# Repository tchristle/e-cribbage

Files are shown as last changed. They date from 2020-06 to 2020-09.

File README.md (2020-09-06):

# e-cribbage
SMT LED Cribbage Board
3D

**To-Do List**
**-----------------------------------------------------------------**
* Schematic
	- [x] assign different symbols to P1 and P2 LEDs
	- [x] assign correct parts numbers to switch and CR2032 symbols
	- [ ] assign final values to LED current limiting resistor
* Layout
	- [x] modify CR2032 footprint to match selected clip
	- [x] modify B5 footprint to match selected slide switch
	- [x] assign common footprint to all capacitors
	- [x] update footprint for S1-S4 tactile push buttons
	- [x] generate gerbers and drill
	- [ ] fix up silk screen on foot prints
* Mechanical
	- [ ] design acrylic cover
	- [ ] update view showing current buttons
* BOM
	- [x] generate BOM from KiCAD schematic
	- [ ] attach Digikey PNs to BOM
	- [X] down select LEDs and colors
	- [x] down select slide switch
	- [x] down select tactile push button
	- [ ] generate Digikey cart from BOM
	- [x] get pricing on PCB
	- [x] get pricing on stencils
	- [ ] get pricing on pick and place assembly
* Software
	- [ ] debug flash store and recall functions
	- [ ] replace for loops and counters with timers in LPM0
	- [X] implement peg swap timer
	- [X] implement Elapsed Time Indicator
* Prototype
	- [x] drive sample LEDs with limit resistor to set brightness level
	- [X] analyze battery life with CR2032 cell
	- [x] interface ez430 with single shifter register

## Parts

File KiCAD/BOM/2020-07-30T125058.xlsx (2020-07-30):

Index | Quantity | Part Number | Manufacturer Part Number | Description | Customer Reference | Available | Backorder | Unit Price | Extended Price USD
1 | 10 | 296-19731-1-ND | MSP430F2012IPWR | IC MCU 16BIT 2KB FLASH 14TSSOP | U2 | 10 | 0 | 1.982 | 19.82
2 | 100 | 296-23258-1-ND | SN74HC595PWR | IC 8BIT SHIFT REGISTER 16-TSSOP | U1,U3-U31 | 100 | 0 | 0.256 | 25.60
3 | 10 | WM17141CT-ND | 0473460001 | CONN RCPT USB2.0 MICRO B SMD R/A | J2 | 10 | 0 | 0.921 | 9.21
4 | 10 | 296-35591-1-ND | TLV71333PDBVR | IC REG LINEAR 3.3V 150MA SOT23-5 | U41 | 10 | 0 | 0.282 | 2.82
5 | 10 | 296-38579-1-ND | TPS22929DDBVR | IC PWR SWITCH P-CHAN 1:1 SOT23-6 | U33 | 10 | 0 | 0.667 | 6.67
6 | 40 | 296-11601-1-ND | SN74LVC1G08DBVR | IC GATE AND 1CH 2-INP SOT23-5 | U32, U34-U40 | 40 | 0 | 0.198 | 7.92
7 | 100 | 399-1099-1-ND | C0603C104M4RACTU | CAP CER 0.1UF 16V X7R 0603 | C1-C39 | 100 | 0 | 0.0154 | 1.54
8 | 20 | 399-7847-1-ND | C0603C105K4RACTU | CAP CER 1UF 16V X7R 0603 | C40-C43 | 20 | 0 | 0.084 | 1.68
9 | 10 | BC-2003-G-TR-CT-ND | BC-2003-G-TR | CR2032 CONTACT STRAP IN GOLD | BAT1 | 10 | 0 | 0.841 | 8.41
10 | 100 | 541-4021-1-ND | CRCW060347K0FKEAC | RES SMD 47K OHM 1% 1/10W 0603 | R251 | 100 | 0 | 0.0134 | 1.34
11 | 100 | 541-10.0KHCT-ND | CRCW060310K0FKEA | RES SMD 10K OHM 1% 1/10W 0603 | R121-R240 | 100 | 0 | 0.0134 | 1.34
12 | 20 | P189-ND | CR2032 | BATTERY LITHIUM 3V COIN 20MM |  | 20 | 0 | 0.2635 | 5.27
13 | 12 | CKN4080-ND | KS11R22CQD | SWITCH PUSH SPST-NO 0.025A 50V | S1-S4 | 12 | 0 | 1.804 | 21.65
14 | 10 | CKN10720CT-ND | JS102011JAQN | SWITCH SLIDE SPDT 300MA 6V | S5 | 10 | 0 | 0.67 | 6.70
15 | 100 | 541-768HCT-ND | CRCW0603768RFKEA | RES SMD 768 OHM 1% 1/10W 0603 | R121-R240 | 100 | 0 | 0.0134 | 1.34

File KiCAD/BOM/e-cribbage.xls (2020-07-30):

Source: |  | /home/travis/e-cribbage/KiCAD/e-cribbage.sch
Date: |  | Wed 29 Jul 2020 05:02:40 PM CDT
Tool: |  | Eeschema 5.1.4+dfsg1-1
Component Count: |  | 577
Ref | QTY | Value | Footprint | Datasheet | Manufacturer | Vendor
BAT1 | 1 | BS-7 | Battery_Holders:Keystone_1058_1x2032-CoinCell | http://www.memoryprotectiondevices.com/datasheets/BS-7-datasheet.pdf | MPD (Memory Protection Devices)
C1-C39 | 39 | 0.1uF | Capacitor_SMD:C_0603_1608Metric_Pad1.05x0.95mm_HandSolder | ~
C40-C43 | 4 | 1.0uF | Capacitor_SMD:C_0603_1608Metric_Pad1.05x0.95mm_HandSolder | ~
D1-D120 | 120 | LED1 | e-cribbage:LED_0603 | ~
D121-D240 | 120 | LED2 | e-cribbage:LED_0603 | ~
J1 | 1 | Conn_01x04_Female | Connector_PinHeader_1.27mm:PinHeader_1x04_P1.27mm_Vertical | ~
J2 | 1 | USB_B_Micro | Connector_USB:USB_Micro-B_Molex_47346-0001 | ~
R1-R120 | 120 | 1k | e-cribbage:R_0603 | ~
R121-R240 | 120 | 1k | e-cribbage:R_0603 | ~
R243, R244, R246, R247 | 4 | 10k | e-cribbage:R_0603 | ~
R251 | 1 | 47k | e-cribbage:R_0603 | ~
S1-S4 | 4 | GPTS203211B | Buttons_Switches_SMD:SW_SPST_B3SL-1002P | http://switches-connectors-custom.cwind.com/Asset/GPTS203211BR2.pdf | CW Industries
S5 | 1 | EG1218 | Button_Switch_SMD:SW_SPDT_CK-JS102011SAQN | http://spec_sheets.e-switch.com/specs/P040040.pdf | E-Switch
U1,U3-U31 | 30 | 74HC595D_118 | digikey-footprints:TSSOP-16_W4.40mm | https://assets.nexperia.com/documents/data-sheet/74HC_HCT595.pdf | Nexperia USA Inc.
U2 | 1 | MSP430F2012IPW | digikey-footprints:TSSOP-14_W4.4mm | http://www.ti.com/lit/ds/symlink/msp430f2012.pdf
U32, U34-U40 | 8 | SN74LVC1G08DBVR | digikey-footprints:SOT-753 | http://www.ti.com/general/docs/suppproductinfo.tsp?distId=10 | Texas Instruments
U41 | 1 | TLV71333PDBV | Package_TO_SOT_SMD:SOT-23-5 | http://www.ti.com/lit/ds/symlink/tlv713p.pdf
U33 | 1 | TPS22929D | Package_TO_SOT_SMD:SOT-23-6 | http://www.ti.com/lit/ds/symlink/tps22929d.pdf

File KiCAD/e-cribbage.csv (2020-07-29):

Source: | /home/travis/e-cribbage/KiCAD/e-cribbage.sch
Date: | Wed 29 Jul 2020 05:02:40 PM CDT
Tool: | Eeschema 5.1.4+dfsg1-1
Component Count: | 577
Ref | Value | Footprint | Datasheet | Manufacturer | Vendor
BAT1 | BS-7 | Battery_Holders:Keystone_1058_1x2032-CoinCell | http://www.memoryprotectiondevices.com/datasheets/BS-7-datasheet.pdf | MPD (Memory Protection Devices)
C1 | 1.0uF | Capacitor_SMD:C_0603_1608Metric_Pad1.05x0.95mm_HandSolder | ~
C2 | 1.0uF | Capacitor_SMD:C_0603_1608Metric_Pad1.05x0.95mm_HandSolder | ~
C3 | 1.0uF | Capacitor_SMD:C_0603_1608Metric_Pad1.05x0.95mm_HandSolder | ~
C4 | 1.0uF | Capacitor_SMD:C_0603_1608Metric_Pad1.05x0.95mm_HandSolder | ~
C5 | 1.0uF | Capacitor_SMD:C_0603_1608Metric_Pad1.05x0.95mm_HandSolder | ~
C6 | 1.0uF | Capacitor_SMD:C_0603_1608Metric_Pad1.05x0.95mm_HandSolder | ~
C7 | 1.0uF | Capacitor_SMD:C_0603_1608Metric_Pad1.05x0.95mm_HandSolder | ~
C8 | 1.0uF | Capacitor_SMD:C_0603_1608Metric_Pad1.05x0.95mm_HandSolder | ~
C9 | 1.0uF | Capacitor_SMD:C_0603_1608Metric_Pad1.05x0.95mm_HandSolder | ~
C10 | 1.0uF | Capacitor_SMD:C_0603_1608Metric_Pad1.05x0.95mm_HandSolder | ~
C11 | 1.0uF | Capacitor_SMD:C_0603_1608Metric_Pad1.05x0.95mm_HandSolder | ~
C12 | 1.0uF | Capacitor_SMD:C_0603_1608Metric_Pad1.05x0.95mm_HandSolder | ~
C13 | 1.0uF | Capacitor_SMD:C_0603_1608Metric_Pad1.05x0.95mm_HandSolder | ~
C14 | 1.0uF | Capacitor_SMD:C_0603_1608Metric_Pad1.05x0.95mm_HandSolder | ~
C15 | 1.0uF | Capacitor_SMD:C_0603_1608Metric_Pad1.05x0.95mm_HandSolder | ~
C16 | 1.0uF | Capacitor_SMD:C_0603_1608Metric_Pad1.05x0.95mm_HandSolder | ~
C17 | 1.0uF | Capacitor_SMD:C_0603_1608Metric_Pad1.05x0.95mm_HandSolder | ~
C18 | 1.0uF | Capacitor_SMD:C_0603_1608Metric_Pad1.05x0.95mm_HandSolder | ~
C19 | 1.0uF | Capacitor_SMD:C_0603_1608Metric_Pad1.05x0.95mm_HandSolder | ~
C20 | 1.0uF | Capacitor_SMD:C_0603_1608Metric_Pad1.05x0.95mm_HandSolder | ~
C21 | 1.0uF | Capacitor_SMD:C_0603_1608Metric_Pad1.05x0.95mm_HandSolder | ~
C22 | 1.0uF | Capacitor_SMD:C_0603_1608Metric_Pad1.05x0.95mm_HandSolder | ~
C23 | 1.0uF | Capacitor_SMD:C_0603_1608Metric_Pad1.05x0.95mm_HandSolder | ~
C24 | 1.0uF | Capacitor_SMD:C_0603_1608Metric_Pad1.05x0.95mm_HandSolder | ~
C25 | 1.0uF | Capacitor_SMD:C_0603_1608Metric_Pad1.05x0.95mm_HandSolder | ~
C26 | 1.0uF | Capacitor_SMD:C_0603_1608Metric_Pad1.05x0.95mm_HandSolder | ~
C27 | 1.0uF | Capacitor_SMD:C_0603_1608Metric_Pad1.05x0.95mm_HandSolder | ~
C28 | 1.0uF | Capacitor_SMD:C_0603_1608Metric_Pad1.05x0.95mm_HandSolder | ~
C29 | 1.0uF | Capacitor_SMD:C_0603_1608Metric_Pad1.05x0.95mm_HandSolder | ~
C30 | 1.0uF | Capacitor_SMD:C_0603_1608Metric_Pad1.05x0.95mm_HandSolder | ~
C31 | 1.0uF | Capacitor_SMD:C_0603_1608Metric_Pad1.05x0.95mm_HandSolder | ~
C32 | 1.0uF | Capacitor_SMD:C_0603_1608Metric_Pad1.05x0.95mm_HandSolder | ~
C33 | 1.0uF | Capacitor_SMD:C_0603_1608Metric_Pad1.05x0.95mm_HandSolder | ~
C34 | 1.0uF | Capacitor_SMD:C_0603_1608Metric_Pad1.05x0.95mm_HandSolder | ~
C35 | 1.0uF | Capacitor_SMD:C_0603_1608Metric_Pad1.05x0.95mm_HandSolder | ~
C36 | 1.0uF | Capacitor_SMD:C_0603_1608Metric_Pad1.05x0.95mm_HandSolder | ~
C37 | 1.0uF | Capacitor_SMD:C_0603_1608Metric_Pad1.05x0.95mm_HandSolder | ~
C38 | 1.0uF | Capacitor_SMD:C_0603_1608Metric_Pad1.05x0.95mm_HandSolder | ~
C39 | 1.0uF | Capacitor_SMD:C_0603_1608Metric_Pad1.05x0.95mm_HandSolder | ~
C40 | 1.0uF | Capacitor_SMD:C_0603_1608Metric_Pad1.05x0.95mm_HandSolder | ~
C41 | 1.0uF | Capacitor_SMD:C_0603_1608Metric_Pad1.05x0.95mm_HandSolder | ~
C42 | 1.0uF | Capacitor_SMD:C_0603_1608Metric_Pad1.05x0.95mm_HandSolder | ~
C43 | 1.0uF | Capacitor_SMD:C_0603_1608Metric_Pad1.05x0.95mm_HandSolder | ~
D1 | LED1 | e-cribbage:LED_0603 | ~
D2 | LED1 | e-cribbage:LED_0603 | ~
D3 | LED1 | e-cribbage:LED_0603 | ~
D4 | LED1 | e-cribbage:LED_0603 | ~
D5 | LED1 | e-cribbage:LED_0603 | ~
D6 | LED1 | e-cribbage:LED_0603 | ~
D7 | LED1 | e-cribbage:LED_0603 | ~
D8 | LED1 | e-cribbage:LED_0603 | ~
D9 | LED1 | e-cribbage:LED_0603 | ~
D10 | LED1 | e-cribbage:LED_0603 | ~
D11 | LED1 | e-cribbage:LED_0603 | ~
D12 | LED1 | e-cribbage:LED_0603 | ~
D13 | LED1 | e-cribbage:LED_0603 | ~
D14 | LED1 | e-cribbage:LED_0603 | ~
D15 | LED1 | e-cribbage:LED_0603 | ~
D16 | LED1 | e-cribbage:LED_0603 | ~
D17 | LED1 | e-cribbage:LED_0603 | ~
D18 | LED1 | e-cribbage:LED_0603 | ~
D19 | LED1 | e-cribbage:LED_0603 | ~
D20 | LED1 | e-cribbage:LED_0603 | ~
D21 | LED1 | e-cribbage:LED_0603 | ~
D22 | LED1 | e-cribbage:LED_0603 | ~
D23 | LED1 | e-cribbage:LED_0603 | ~
D24 | LED1 | e-cribbage:LED_0603 | ~
D25 | LED1 | e-cribbage:LED_0603 | ~
D26 | LED1 | e-cribbage:LED_0603 | ~
D27 | LED1 | e-cribbage:LED_0603 | ~
D28 | LED1 | e-cribbage:LED_0603 | ~
D29 | LED1 | e-cribbage:LED_0603 | ~
D30 | LED1 | e-cribbage:LED_0603 | ~
D31 | LED1 | e-cribbage:LED_0603 | ~
D32 | LED1 | e-cribbage:LED_0603 | ~
D33 | LED1 | e-cribbage:LED_0603 | ~
D34 | LED1 | e-cribbage:LED_0603 | ~
D35 | LED1 | e-cribbage:LED_0603 | ~
D36 | LED1 | e-cribbage:LED_0603 | ~
D37 | LED1 | e-cribbage:LED_0603 | ~
D38 | LED1 | e-cribbage:LED_0603 | ~
D39 | LED1 | e-cribbage:LED_0603 | ~
D40 | LED1 | e-cribbage:LED_0603 | ~
D41 | LED1 | e-cribbage:LED_0603 | ~
D42 | LED1 | e-cribbage:LED_0603 | ~
D43 | LED1 | e-cribbage:LED_0603 | ~
D44 | LED1 | e-cribbage:LED_0603 | ~
D45 | LED1 | e-cribbage:LED_0603 | ~
D46 | LED1 | e-cribbage:LED_0603 | ~
D47 | LED1 | e-cribbage:LED_0603 | ~
D48 | LED1 | e-cribbage:LED_0603 | ~
D49 | LED1 | e-cribbage:LED_0603 | ~
D50 | LED1 | e-cribbage:LED_0603 | ~
D51 | LED1 | e-cribbage:LED_0603 | ~
D52 | LED1 | e-cribbage:LED_0603 | ~
D53 | LED1 | e-cribbage:LED_0603 | ~
D54 | LED1 | e-cribbage:LED_0603 | ~
D55 | LED1 | e-cribbage:LED_0603 | ~
D56 | LED1 | e-cribbage:LED_0603 | ~
D57 | LED1 | e-cribbage:LED_0603 | ~
D58 | LED1 | e-cribbage:LED_0603 | ~
D59 | LED1 | e-cribbage:LED_0603 | ~
D60 | LED1 | e-cribbage:LED_0603 | ~
D61 | LED1 | e-cribbage:LED_0603 | ~
D62 | LED1 | e-cribbage:LED_0603 | ~
D63 | LED1 | e-cribbage:LED_0603 | ~
D64 | LED1 | e-cribbage:LED_0603 | ~
D65 | LED1 | e-cribbage:LED_0603 | ~
D66 | LED1 | e-cribbage:LED_0603 | ~
D67 | LED1 | e-cribbage:LED_0603 | ~
D68 | LED1 | e-cribbage:LED_0603 | ~
D69 | LED1 | e-cribbage:LED_0603 | ~
D70 | LED1 | e-cribbage:LED_0603 | ~
D71 | LED1 | e-cribbage:LED_0603 | ~
D72 | LED1 | e-cribbage:LED_0603 | ~
D73 | LED1 | e-cribbage:LED_0603 | ~
D74 | LED1 | e-cribbage:LED_0603 | ~
D75 | LED1 | e-cribbage:LED_0603 | ~
D76 | LED1 | e-cribbage:LED_0603 | ~
D77 | LED1 | e-cribbage:LED_0603 | ~
D78 | LED1 | e-cribbage:LED_0603 | ~
D79 | LED1 | e-cribbage:LED_0603 | ~
D80 | LED1 | e-cribbage:LED_0603 | ~
D81 | LED1 | e-cribbage:LED_0603 | ~
D82 | LED1 | e-cribbage:LED_0603 | ~
D83 | LED1 | e-cribbage:LED_0603 | ~
D84 | LED1 | e-cribbage:LED_0603 | ~
D85 | LED1 | e-cribbage:LED_0603 | ~
D86 | LED1 | e-cribbage:LED_0603 | ~
D87 | LED1 | e-cribbage:LED_0603 | ~
D88 | LED1 | e-cribbage:LED_0603 | ~
D89 | LED1 | e-cribbage:LED_0603 | ~
D90 | LED1 | e-cribbage:LED_0603 | ~
D91 | LED1 | e-cribbage:LED_0603 | ~
D92 | LED1 | e-cribbage:LED_0603 | ~
D93 | LED1 | e-cribbage:LED_0603 | ~
D94 | LED1 | e-cribbage:LED_0603 | ~
D95 | LED1 | e-cribbage:LED_0603 | ~
D96 | LED1 | e-cribbage:LED_0603 | ~
D97 | LED1 | e-cribbage:LED_0603 | ~
D98 | LED1 | e-cribbage:LED_0603 | ~
D99 | LED1 | e-cribbage:LED_0603 | ~
D100 | LED1 | e-cribbage:LED_0603 | ~
D101 | LED1 | e-cribbage:LED_0603 | ~
D102 | LED1 | e-cribbage:LED_0603 | ~
D103 | LED1 | e-cribbage:LED_0603 | ~
D104 | LED1 | e-cribbage:LED_0603 | ~
D105 | LED1 | e-cribbage:LED_0603 | ~
D106 | LED1 | e-cribbage:LED_0603 | ~
D107 | LED1 | e-cribbage:LED_0603 | ~
D108 | LED1 | e-cribbage:LED_0603 | ~
D109 | LED1 | e-cribbage:LED_0603 | ~
D110 | LED1 | e-cribbage:LED_0603 | ~
D111 | LED1 | e-cribbage:LED_0603 | ~
D112 | LED1 | e-cribbage:LED_0603 | ~
D113 | LED1 | e-cribbage:LED_0603 | ~
D114 | LED1 | e-cribbage:LED_0603 | ~
D115 | LED1 | e-cribbage:LED_0603 | ~
D116 | LED1 | e-cribbage:LED_0603 | ~
D117 | LED1 | e-cribbage:LED_0603 | ~
D118 | LED1 | e-cribbage:LED_0603 | ~
D119 | LED1 | e-cribbage:LED_0603 | ~
D120 | LED1 | e-cribbage:LED_0603 | ~
D121 | LED2 | e-cribbage:LED_0603 | ~
D122 | LED2 | e-cribbage:LED_0603 | ~
D123 | LED2 | e-cribbage:LED_0603 | ~
D124 | LED2 | e-cribbage:LED_0603 | ~
D125 | LED2 | e-cribbage:LED_0603 | ~
D126 | LED2 | e-cribbage:LED_0603 | ~
D127 | LED2 | e-cribbage:LED_0603 | ~
D128 | LED2 | e-cribbage:LED_0603 | ~
D129 | LED2 | e-cribbage:LED_0603 | ~
D130 | LED2 | e-cribbage:LED_0603 | ~
D131 | LED2 | e-cribbage:LED_0603 | ~
D132 | LED2 | e-cribbage:LED_0603 | ~
D133 | LED2 | e-cribbage:LED_0603 | ~
D134 | LED2 | e-cribbage:LED_0603 | ~
D135 | LED2 | e-cribbage:LED_0603 | ~
D136 | LED2 | e-cribbage:LED_0603 | ~
D137 | LED2 | e-cribbage:LED_0603 | ~
D138 | LED2 | e-cribbage:LED_0603 | ~
D139 | LED2 | e-cribbage:LED_0603 | ~
D140 | LED2 | e-cribbage:LED_0603 | ~
D141 | LED2 | e-cribbage:LED_0603 | ~
D142 | LED2 | e-cribbage:LED_0603 | ~
D143 | LED2 | e-cribbage:LED_0603 | ~
D144 | LED2 | e-cribbage:LED_0603 | ~
D145 | LED2 | e-cribbage:LED_0603 | ~
D146 | LED2 | e-cribbage:LED_0603 | ~
D147 | LED2 | e-cribbage:LED_0603 | ~
D148 | LED2 | e-cribbage:LED_0603 | ~
D149 | LED2 | e-cribbage:LED_0603 | ~
D150 | LED2 | e-cribbage:LED_0603 | ~
D151 | LED2 | e-cribbage:LED_0603 | ~
D152 | LED2 | e-cribbage:LED_0603 | ~
D153 | LED2 | e-cribbage:LED_0603 | ~
D154 | LED2 | e-cribbage:LED_0603 | ~
D155 | LED2 | e-cribbage:LED_0603 | ~
D156 | LED2 | e-cribbage:LED_0603 | ~
D157 | LED2 | e-cribbage:LED_0603 | ~
D158 | LED2 | e-cribbage:LED_0603 | ~
D159 | LED2 | e-cribbage:LED_0603 | ~
D160 | LED2 | e-cribbage:LED_0603 | ~
D161 | LED2 | e-cribbage:LED_0603 | ~
D162 | LED2 | e-cribbage:LED_0603 | ~
D163 | LED2 | e-cribbage:LED_0603 | ~
D164 | LED2 | e-cribbage:LED_0603 | ~
D165 | LED2 | e-cribbage:LED_0603 | ~
D166 | LED2 | e-cribbage:LED_0603 | ~
D167 | LED2 | e-cribbage:LED_0603 | ~
D168 | LED2 | e-cribbage:LED_0603 | ~
D169 | LED2 | e-cribbage:LED_0603 | ~
D170 | LED2 | e-cribbage:LED_0603 | ~
D171 | LED2 | e-cribbage:LED_0603 | ~
D172 | LED2 | e-cribbage:LED_0603 | ~
D173 | LED2 | e-cribbage:LED_0603 | ~
D174 | LED2 | e-cribbage:LED_0603 | ~
D175 | LED2 | e-cribbage:LED_0603 | ~
D176 | LED2 | e-cribbage:LED_0603 | ~
D177 | LED2 | e-cribbage:LED_0603 | ~
D178 | LED2 | e-cribbage:LED_0603 | ~
D179 | LED2 | e-cribbage:LED_0603 | ~
D180 | LED2 | e-cribbage:LED_0603 | ~
D181 | LED2 | e-cribbage:LED_0603 | ~
D182 | LED2 | e-cribbage:LED_0603 | ~
D183 | LED2 | e-cribbage:LED_0603 | ~
D184 | LED2 | e-cribbage:LED_0603 | ~
D185 | LED2 | e-cribbage:LED_0603 | ~
D186 | LED2 | e-cribbage:LED_0603 | ~
D187 | LED2 | e-cribbage:LED_0603 | ~
D188 | LED2 | e-cribbage:LED_0603 | ~
D189 | LED2 | e-cribbage:LED_0603 | ~
D190 | LED2 | e-cribbage:LED_0603 | ~
D191 | LED2 | e-cribbage:LED_0603 | ~
D192 | LED2 | e-cribbage:LED_0603 | ~
D193 | LED2 | e-cribbage:LED_0603 | ~
D194 | LED2 | e-cribbage:LED_0603 | ~
D195 | LED2 | e-cribbage:LED_0603 | ~
D196 | LED2 | e-cribbage:LED_0603 | ~
D197 | LED2 | e-cribbage:LED_0603 | ~
D198 | LED2 | e-cribbage:LED_0603 | ~
D199 | LED2 | e-cribbage:LED_0603 | ~
D200 | LED2 | e-cribbage:LED_0603 | ~
D201 | LED2 | e-cribbage:LED_0603 | ~
D202 | LED2 | e-cribbage:LED_0603 | ~
D203 | LED2 | e-cribbage:LED_0603 | ~
D204 | LED2 | e-cribbage:LED_0603 | ~
D205 | LED2 | e-cribbage:LED_0603 | ~
D206 | LED2 | e-cribbage:LED_0603 | ~
D207 | LED2 | e-cribbage:LED_0603 | ~
D208 | LED2 | e-cribbage:LED_0603 | ~
D209 | LED2 | e-cribbage:LED_0603 | ~
D210 | LED2 | e-cribbage:LED_0603 | ~
D211 | LED2 | e-cribbage:LED_0603 | ~
D212 | LED2 | e-cribbage:LED_0603 | ~
D213 | LED2 | e-cribbage:LED_0603 | ~
D214 | LED2 | e-cribbage:LED_0603 | ~
D215 | LED2 | e-cribbage:LED_0603 | ~
D216 | LED2 | e-cribbage:LED_0603 | ~
D217 | LED2 | e-cribbage:LED_0603 | ~
D218 | LED2 | e-cribbage:LED_0603 | ~
D219 | LED2 | e-cribbage:LED_0603 | ~
D220 | LED2 | e-cribbage:LED_0603 | ~
D221 | LED2 | e-cribbage:LED_0603 | ~
D222 | LED2 | e-cribbage:LED_0603 | ~
D223 | LED2 | e-cribbage:LED_0603 | ~
D224 | LED2 | e-cribbage:LED_0603 | ~
D225 | LED2 | e-cribbage:LED_0603 | ~
D226 | LED2 | e-cribbage:LED_0603 | ~
D227 | LED2 | e-cribbage:LED_0603 | ~
D228 | LED2 | e-cribbage:LED_0603 | ~
D229 | LED2 | e-cribbage:LED_0603 | ~
D230 | LED2 | e-cribbage:LED_0603 | ~
D231 | LED2 | e-cribbage:LED_0603 | ~
D232 | LED2 | e-cribbage:LED_0603 | ~
D233 | LED2 | e-cribbage:LED_0603 | ~
D234 | LED2 | e-cribbage:LED_0603 | ~
D235 | LED2 | e-cribbage:LED_0603 | ~
D236 | LED2 | e-cribbage:LED_0603 | ~
D237 | LED2 | e-cribbage:LED_0603 | ~
D238 | LED2 | e-cribbage:LED_0603 | ~
D239 | LED2 | e-cribbage:LED_0603 | ~
D240 | LED2 | e-cribbage:LED_0603 | ~
J1 | Conn_01x04_Female | Connector_PinHeader_1.27mm:PinHeader_1x04_P1.27mm_Vertical | ~
J2 | USB_B_Micro | Connector_USB:USB_Micro-B_Molex_47346-0001 | ~
R1 | 1k | e-cribbage:R_0603 | ~
R2 | 1k | e-cribbage:R_0603 | ~
R3 | 1k | e-cribbage:R_0603 | ~
R4 | 1k | e-cribbage:R_0603 | ~
R5 | 1k | e-cribbage:R_0603 | ~
R6 | 1k | e-cribbage:R_0603 | ~
R7 | 1k | e-cribbage:R_0603 | ~
R8 | 1k | e-cribbage:R_0603 | ~
R9 | 1k | e-cribbage:R_0603 | ~
R10 | 1k | e-cribbage:R_0603 | ~
R11 | 1k | e-cribbage:R_0603 | ~
R12 | 1k | e-cribbage:R_0603 | ~
R13 | 1k | e-cribbage:R_0603 | ~
R14 | 1k | e-cribbage:R_0603 | ~
R15 | 1k | e-cribbage:R_0603 | ~
R16 | 1k | e-cribbage:R_0603 | ~
R17 | 1k | e-cribbage:R_0603 | ~
R18 | 1k | e-cribbage:R_0603 | ~
R19 | 1k | e-cribbage:R_0603 | ~
R20 | 1k | e-cribbage:R_0603 | ~
R21 | 1k | e-cribbage:R_0603 | ~
R22 | 1k | e-cribbage:R_0603 | ~
R23 | 1k | e-cribbage:R_0603 | ~
R24 | 1k | e-cribbage:R_0603 | ~
R25 | 1k | e-cribbage:R_0603 | ~
R26 | 1k | e-cribbage:R_0603 | ~
R27 | 1k | e-cribbage:R_0603 | ~
R28 | 1k | e-cribbage:R_0603 | ~
R29 | 1k | e-cribbage:R_0603 | ~
R30 | 1k | e-cribbage:R_0603 | ~
R31 | 1k | e-cribbage:R_0603 | ~
R32 | 1k | e-cribbage:R_0603 | ~
R33 | 1k | e-cribbage:R_0603 | ~
R34 | 1k | e-cribbage:R_0603 | ~
R35 | 1k | e-cribbage:R_0603 | ~
R36 | 1k | e-cribbage:R_0603 | ~
R37 | 1k | e-cribbage:R_0603 | ~
R38 | 1k | e-cribbage:R_0603 | ~
R39 | 1k | e-cribbage:R_0603 | ~
R40 | 1k | e-cribbage:R_0603 | ~
R41 | 1k | e-cribbage:R_0603 | ~
R42 | 1k | e-cribbage:R_0603 | ~
R43 | 1k | e-cribbage:R_0603 | ~
R44 | 1k | e-cribbage:R_0603 | ~
R45 | 1k | e-cribbage:R_0603 | ~
R46 | 1k | e-cribbage:R_0603 | ~
R47 | 1k | e-cribbage:R_0603 | ~
R48 | 1k | e-cribbage:R_0603 | ~
R49 | 1k | e-cribbage:R_0603 | ~
R50 | 1k | e-cribbage:R_0603 | ~
R51 | 1k | e-cribbage:R_0603 | ~
R52 | 1k | e-cribbage:R_0603 | ~
R53 | 1k | e-cribbage:R_0603 | ~
R54 | 1k | e-cribbage:R_0603 | ~
R55 | 1k | e-cribbage:R_0603 | ~
R56 | 1k | e-cribbage:R_0603 | ~
R57 | 1k | e-cribbage:R_0603 | ~
R58 | 1k | e-cribbage:R_0603 | ~
R59 | 1k | e-cribbage:R_0603 | ~
R60 | 1k | e-cribbage:R_0603 | ~
R61 | 1k | e-cribbage:R_0603 | ~
R62 | 1k | e-cribbage:R_0603 | ~
R63 | 1k | e-cribbage:R_0603 | ~
R64 | 1k | e-cribbage:R_0603 | ~
R65 | 1k | e-cribbage:R_0603 | ~
R66 | 1k | e-cribbage:R_0603 | ~
R67 | 1k | e-cribbage:R_0603 | ~
R68 | 1k | e-cribbage:R_0603 | ~
R69 | 1k | e-cribbage:R_0603 | ~
R70 | 1k | e-cribbage:R_0603 | ~
R71 | 1k | e-cribbage:R_0603 | ~
R72 | 1k | e-cribbage:R_0603 | ~
R73 | 1k | e-cribbage:R_0603 | ~
R74 | 1k | e-cribbage:R_0603 | ~
R75 | 1k | e-cribbage:R_0603 | ~
R76 | 1k | e-cribbage:R_0603 | ~
R77 | 1k | e-cribbage:R_0603 | ~
R78 | 1k | e-cribbage:R_0603 | ~
R79 | 1k | e-cribbage:R_0603 | ~
R80 | 1k | e-cribbage:R_0603 | ~
R81 | 1k | e-cribbage:R_0603 | ~
R82 | 1k | e-cribbage:R_0603 | ~
R83 | 1k | e-cribbage:R_0603 | ~
R84 | 1k | e-cribbage:R_0603 | ~
R85 | 1k | e-cribbage:R_0603 | ~
R86 | 1k | e-cribbage:R_0603 | ~
R87 | 1k | e-cribbage:R_0603 | ~
R88 | 1k | e-cribbage:R_0603 | ~
R89 | 1k | e-cribbage:R_0603 | ~
R90 | 1k | e-cribbage:R_0603 | ~
R91 | 1k | e-cribbage:R_0603 | ~
R92 | 1k | e-cribbage:R_0603 | ~
R93 | 1k | e-cribbage:R_0603 | ~
R94 | 1k | e-cribbage:R_0603 | ~
R95 | 1k | e-cribbage:R_0603 | ~
R96 | 1k | e-cribbage:R_0603 | ~
R97 | 1k | e-cribbage:R_0603 | ~
R98 | 1k | e-cribbage:R_0603 | ~
R99 | 1k | e-cribbage:R_0603 | ~
R100 | 1k | e-cribbage:R_0603 | ~
R101 | 1k | e-cribbage:R_0603 | ~
R102 | 1k | e-cribbage:R_0603 | ~
R103 | 1k | e-cribbage:R_0603 | ~
R104 | 1k | e-cribbage:R_0603 | ~
R105 | 1k | e-cribbage:R_0603 | ~
R106 | 1k | e-cribbage:R_0603 | ~
R107 | 1k | e-cribbage:R_0603 | ~
R108 | 1k | e-cribbage:R_0603 | ~
R109 | 1k | e-cribbage:R_0603 | ~
R110 | 1k | e-cribbage:R_0603 | ~
R111 | 1k | e-cribbage:R_0603 | ~
R112 | 1k | e-cribbage:R_0603 | ~
R113 | 1k | e-cribbage:R_0603 | ~
R114 | 1k | e-cribbage:R_0603 | ~
R115 | 1k | e-cribbage:R_0603 | ~
R116 | 1k | e-cribbage:R_0603 | ~
R117 | 1k | e-cribbage:R_0603 | ~
R118 | 1k | e-cribbage:R_0603 | ~
R119 | 1k | e-cribbage:R_0603 | ~
R120 | 1k | e-cribbage:R_0603 | ~
R121 | 1k | e-cribbage:R_0603 | ~
R122 | 1k | e-cribbage:R_0603 | ~
R123 | 1k | e-cribbage:R_0603 | ~
R124 | 1k | e-cribbage:R_0603 | ~
R125 | 1k | e-cribbage:R_0603 | ~
R126 | 1k | e-cribbage:R_0603 | ~
R127 | 1k | e-cribbage:R_0603 | ~
R128 | 1k | e-cribbage:R_0603 | ~
R129 | 1k | e-cribbage:R_0603 | ~
R130 | 1k | e-cribbage:R_0603 | ~
R131 | 1k | e-cribbage:R_0603 | ~
R132 | 1k | e-cribbage:R_0603 | ~
R133 | 1k | e-cribbage:R_0603 | ~
R134 | 1k | e-cribbage:R_0603 | ~
R135 | 1k | e-cribbage:R_0603 | ~
R136 | 1k | e-cribbage:R_0603 | ~
R137 | 1k | e-cribbage:R_0603 | ~
R138 | 1k | e-cribbage:R_0603 | ~
R139 | 1k | e-cribbage:R_0603 | ~
R140 | 1k | e-cribbage:R_0603 | ~
R141 | 1k | e-cribbage:R_0603 | ~
R142 | 1k | e-cribbage:R_0603 | ~
R143 | 1k | e-cribbage:R_0603 | ~
R144 | 1k | e-cribbage:R_0603 | ~
R145 | 1k | e-cribbage:R_0603 | ~
R146 | 1k | e-cribbage:R_0603 | ~
R147 | 1k | e-cribbage:R_0603 | ~
R148 | 1k | e-cribbage:R_0603 | ~
R149 | 1k | e-cribbage:R_0603 | ~
R150 | 1k | e-cribbage:R_0603 | ~
R151 | 1k | e-cribbage:R_0603 | ~
R152 | 1k | e-cribbage:R_0603 | ~
R153 | 1k | e-cribbage:R_0603 | ~
R154 | 1k | e-cribbage:R_0603 | ~
R155 | 1k | e-cribbage:R_0603 | ~
R156 | 1k | e-cribbage:R_0603 | ~
R157 | 1k | e-cribbage:R_0603 | ~
R158 | 1k | e-cribbage:R_0603 | ~
R159 | 1k | e-cribbage:R_0603 | ~
R160 | 1k | e-cribbage:R_0603 | ~
R161 | 1k | e-cribbage:R_0603 | ~
R162 | 1k | e-cribbage:R_0603 | ~
R163 | 1k | e-cribbage:R_0603 | ~
R164 | 1k | e-cribbage:R_0603 | ~
R165 | 1k | e-cribbage:R_0603 | ~
R166 | 1k | e-cribbage:R_0603 | ~
R167 | 1k | e-cribbage:R_0603 | ~
R168 | 1k | e-cribbage:R_0603 | ~
R169 | 1k | e-cribbage:R_0603 | ~
R170 | 1k | e-cribbage:R_0603 | ~
R171 | 1k | e-cribbage:R_0603 | ~
R172 | 1k | e-cribbage:R_0603 | ~
R173 | 1k | e-cribbage:R_0603 | ~
R174 | 1k | e-cribbage:R_0603 | ~
R175 | 1k | e-cribbage:R_0603 | ~
R176 | 1k | e-cribbage:R_0603 | ~
R177 | 1k | e-cribbage:R_0603 | ~
R178 | 1k | e-cribbage:R_0603 | ~
R179 | 1k | e-cribbage:R_0603 | ~
R180 | 1k | e-cribbage:R_0603 | ~
R181 | 1k | e-cribbage:R_0603 | ~
R182 | 1k | e-cribbage:R_0603 | ~
R183 | 1k | e-cribbage:R_0603 | ~
R184 | 1k | e-cribbage:R_0603 | ~
R185 | 1k | e-cribbage:R_0603 | ~
R186 | 1k | e-cribbage:R_0603 | ~
R187 | 1k | e-cribbage:R_0603 | ~
R188 | 1k | e-cribbage:R_0603 | ~
R189 | 1k | e-cribbage:R_0603 | ~
R190 | 1k | e-cribbage:R_0603 | ~
R191 | 1k | e-cribbage:R_0603 | ~
R192 | 1k | e-cribbage:R_0603 | ~
R193 | 1k | e-cribbage:R_0603 | ~
R194 | 1k | e-cribbage:R_0603 | ~
R195 | 1k | e-cribbage:R_0603 | ~
R196 | 1k | e-cribbage:R_0603 | ~
R197 | 1k | e-cribbage:R_0603 | ~
R198 | 1k | e-cribbage:R_0603 | ~
R199 | 1k | e-cribbage:R_0603 | ~
R200 | 1k | e-cribbage:R_0603 | ~
R201 | 1k | e-cribbage:R_0603 | ~
R202 | 1k | e-cribbage:R_0603 | ~
R203 | 1k | e-cribbage:R_0603 | ~
R204 | 1k | e-cribbage:R_0603 | ~
R205 | 1k | e-cribbage:R_0603 | ~
R206 | 1k | e-cribbage:R_0603 | ~
R207 | 1k | e-cribbage:R_0603 | ~
R208 | 1k | e-cribbage:R_0603 | ~
R209 | 1k | e-cribbage:R_0603 | ~
R210 | 1k | e-cribbage:R_0603 | ~
R211 | 1k | e-cribbage:R_0603 | ~
R212 | 1k | e-cribbage:R_0603 | ~
R213 | 1k | e-cribbage:R_0603 | ~
R214 | 1k | e-cribbage:R_0603 | ~
R215 | 1k | e-cribbage:R_0603 | ~
R216 | 1k | e-cribbage:R_0603 | ~
R217 | 1k | e-cribbage:R_0603 | ~
R218 | 1k | e-cribbage:R_0603 | ~
R219 | 1k | e-cribbage:R_0603 | ~
R220 | 1k | e-cribbage:R_0603 | ~
R221 | 1k | e-cribbage:R_0603 | ~
R222 | 1k | e-cribbage:R_0603 | ~
R223 | 1k | e-cribbage:R_0603 | ~
R224 | 1k | e-cribbage:R_0603 | ~
R225 | 1k | e-cribbage:R_0603 | ~
R226 | 1k | e-cribbage:R_0603 | ~
R227 | 1k | e-cribbage:R_0603 | ~
R228 | 1k | e-cribbage:R_0603 | ~
R229 | 1k | e-cribbage:R_0603 | ~
R230 | 1k | e-cribbage:R_0603 | ~
R231 | 1k | e-cribbage:R_0603 | ~
R232 | 1k | e-cribbage:R_0603 | ~
R233 | 1k | e-cribbage:R_0603 | ~
R234 | 1k | e-cribbage:R_0603 | ~
R235 | 1k | e-cribbage:R_0603 | ~
R236 | 1k | e-cribbage:R_0603 | ~
R237 | 1k | e-cribbage:R_0603 | ~
R238 | 1k | e-cribbage:R_0603 | ~
R239 | 1k | e-cribbage:R_0603 | ~
R240 | 1k | e-cribbage:R_0603 | ~
R243 | 10k | e-cribbage:R_0603 | ~
R244 | 10k | e-cribbage:R_0603 | ~
R246 | 10k | e-cribbage:R_0603 | ~
R247 | 10k | e-cribbage:R_0603 | ~
R251 | 47k | e-cribbage:R_0603 | ~
S1 | GPTS203211B | Buttons_Switches_SMD:SW_SPST_B3SL-1002P | http://switches-connectors-custom.cwind.com/Asset/GPTS203211BR2.pdf | CW Industries
S2 | GPTS203211B | Buttons_Switches_SMD:SW_SPST_B3SL-1002P | http://switches-connectors-custom.cwind.com/Asset/GPTS203211BR2.pdf | CW Industries
S3 | GPTS203211B | Buttons_Switches_SMD:SW_SPST_B3SL-1002P | http://switches-connectors-custom.cwind.com/Asset/GPTS203211BR2.pdf | CW Industries
S4 | GPTS203211B | Buttons_Switches_SMD:SW_SPST_B3SL-1002P | http://switches-connectors-custom.cwind.com/Asset/GPTS203211BR2.pdf | CW Industries
S5 | EG1218 | Button_Switch_SMD:SW_SPDT_CK-JS102011SAQN | http://spec_sheets.e-switch.com/specs/P040040.pdf | E-Switch
U1 | 74HC595D_118 | digikey-footprints:TSSOP-16_W4.40mm | https://assets.nexperia.com/documents/data-sheet/74HC_HCT595.pdf | Nexperia USA Inc.
U2 | MSP430F2012IPW | digikey-footprints:TSSOP-14_W4.4mm | http://www.ti.com/lit/ds/symlink/msp430f2012.pdf
U3 | 74HC595D_118 | digikey-footprints:TSSOP-16_W4.40mm | https://assets.nexperia.com/documents/data-sheet/74HC_HCT595.pdf | Nexperia USA Inc.
U4 | 74HC595D_118 | digikey-footprints:TSSOP-16_W4.40mm | https://assets.nexperia.com/documents/data-sheet/74HC_HCT595.pdf | Nexperia USA Inc.
U5 | 74HC595D_118 | digikey-footprints:TSSOP-16_W4.40mm | https://assets.nexperia.com/documents/data-sheet/74HC_HCT595.pdf | Nexperia USA Inc.
U6 | 74HC595D_118 | digikey-footprints:TSSOP-16_W4.40mm | https://assets.nexperia.com/documents/data-sheet/74HC_HCT595.pdf | Nexperia USA Inc.
U7 | 74HC595D_118 | digikey-footprints:TSSOP-16_W4.40mm | https://assets.nexperia.com/documents/data-sheet/74HC_HCT595.pdf | Nexperia USA Inc.
U8 | 74HC595D_118 | digikey-footprints:TSSOP-16_W4.40mm | https://assets.nexperia.com/documents/data-sheet/74HC_HCT595.pdf | Nexperia USA Inc.
U9 | 74HC595D_118 | digikey-footprints:TSSOP-16_W4.40mm | https://assets.nexperia.com/documents/data-sheet/74HC_HCT595.pdf | Nexperia USA Inc.
U10 | 74HC595D_118 | digikey-footprints:TSSOP-16_W4.40mm | https://assets.nexperia.com/documents/data-sheet/74HC_HCT595.pdf | Nexperia USA Inc.
U11 | 74HC595D_118 | digikey-footprints:TSSOP-16_W4.40mm | https://assets.nexperia.com/documents/data-sheet/74HC_HCT595.pdf | Nexperia USA Inc.
U12 | 74HC595D_118 | digikey-footprints:TSSOP-16_W4.40mm | https://assets.nexperia.com/documents/data-sheet/74HC_HCT595.pdf | Nexperia USA Inc.
U13 | 74HC595D_118 | digikey-footprints:TSSOP-16_W4.40mm | https://assets.nexperia.com/documents/data-sheet/74HC_HCT595.pdf | Nexperia USA Inc.
U14 | 74HC595D_118 | digikey-footprints:TSSOP-16_W4.40mm | https://assets.nexperia.com/documents/data-sheet/74HC_HCT595.pdf | Nexperia USA Inc.
U15 | 74HC595D_118 | digikey-footprints:TSSOP-16_W4.40mm | https://assets.nexperia.com/documents/data-sheet/74HC_HCT595.pdf | Nexperia USA Inc.
U16 | 74HC595D_118 | digikey-footprints:TSSOP-16_W4.40mm | https://assets.nexperia.com/documents/data-sheet/74HC_HCT595.pdf | Nexperia USA Inc.
U17 | 74HC595D_118 | digikey-footprints:TSSOP-16_W4.40mm | https://assets.nexperia.com/documents/data-sheet/74HC_HCT595.pdf | Nexperia USA Inc.
U18 | 74HC595D_118 | digikey-footprints:TSSOP-16_W4.40mm | https://assets.nexperia.com/documents/data-sheet/74HC_HCT595.pdf | Nexperia USA Inc.
U19 | 74HC595D_118 | digikey-footprints:TSSOP-16_W4.40mm | https://assets.nexperia.com/documents/data-sheet/74HC_HCT595.pdf | Nexperia USA Inc.
U20 | 74HC595D_118 | digikey-footprints:TSSOP-16_W4.40mm | https://assets.nexperia.com/documents/data-sheet/74HC_HCT595.pdf | Nexperia USA Inc.
U21 | 74HC595D_118 | digikey-footprints:TSSOP-16_W4.40mm | https://assets.nexperia.com/documents/data-sheet/74HC_HCT595.pdf | Nexperia USA Inc.
U22 | 74HC595D_118 | digikey-footprints:TSSOP-16_W4.40mm | https://assets.nexperia.com/documents/data-sheet/74HC_HCT595.pdf | Nexperia USA Inc.
U23 | 74HC595D_118 | digikey-footprints:TSSOP-16_W4.40mm | https://assets.nexperia.com/documents/data-sheet/74HC_HCT595.pdf | Nexperia USA Inc.
U24 | 74HC595D_118 | digikey-footprints:TSSOP-16_W4.40mm | https://assets.nexperia.com/documents/data-sheet/74HC_HCT595.pdf | Nexperia USA Inc.
U25 | 74HC595D_118 | digikey-footprints:TSSOP-16_W4.40mm | https://assets.nexperia.com/documents/data-sheet/74HC_HCT595.pdf | Nexperia USA Inc.
U26 | 74HC595D_118 | digikey-footprints:TSSOP-16_W4.40mm | https://assets.nexperia.com/documents/data-sheet/74HC_HCT595.pdf | Nexperia USA Inc.
U27 | 74HC595D_118 | digikey-footprints:TSSOP-16_W4.40mm | https://assets.nexperia.com/documents/data-sheet/74HC_HCT595.pdf | Nexperia USA Inc.
U28 | 74HC595D_118 | digikey-footprints:TSSOP-16_W4.40mm | https://assets.nexperia.com/documents/data-sheet/74HC_HCT595.pdf | Nexperia USA Inc.
U29 | 74HC595D_118 | digikey-footprints:TSSOP-16_W4.40mm | https://assets.nexperia.com/documents/data-sheet/74HC_HCT595.pdf | Nexperia USA Inc.
U30 | 74HC595D_118 | digikey-footprints:TSSOP-16_W4.40mm | https://assets.nexperia.com/documents/data-sheet/74HC_HCT595.pdf | Nexperia USA Inc.
U31 | 74HC595D_118 | digikey-footprints:TSSOP-16_W4.40mm | https://assets.nexperia.com/documents/data-sheet/74HC_HCT595.pdf | Nexperia USA Inc.
U32 | SN74LVC1G08DBVR | digikey-footprints:SOT-753 | http://www.ti.com/general/docs/suppproductinfo.tsp?distId=10 | Texas Instruments
U33 | TPS22929D | Package_TO_SOT_SMD:SOT-23-6 | http://www.ti.com/lit/ds/symlink/tps22929d.pdf
U34 | SN74LVC1G08DBVR | digikey-footprints:SOT-753 | http://www.ti.com/general/docs/suppproductinfo.tsp?distId=10 | Texas Instruments
U35 | SN74LVC1G08DBVR | digikey-footprints:SOT-753 | http://www.ti.com/general/docs/suppproductinfo.tsp?distId=10 | Texas Instruments
U36 | SN74LVC1G08DBVR | digikey-footprints:SOT-753 | http://www.ti.com/general/docs/suppproductinfo.tsp?distId=10 | Texas Instruments
U37 | SN74LVC1G08DBVR | digikey-footprints:SOT-753 | http://www.ti.com/general/docs/suppproductinfo.tsp?distId=10 | Texas Instruments
U38 | SN74LVC1G08DBVR | digikey-footprints:SOT-753 | http://www.ti.com/general/docs/suppproductinfo.tsp?distId=10 | Texas Instruments
U39 | SN74LVC1G08DBVR | digikey-footprints:SOT-753 | http://www.ti.com/general/docs/suppproductinfo.tsp?distId=10 | Texas Instruments
U40 | SN74LVC1G08DBVR | digikey-footprints:SOT-753 | http://www.ti.com/general/docs/suppproductinfo.tsp?distId=10 | Texas Instruments
U41 | TLV71333PDBV | Package_TO_SOT_SMD:SOT-23-5 | http://www.ti.com/lit/ds/symlink/tlv713p.pdf

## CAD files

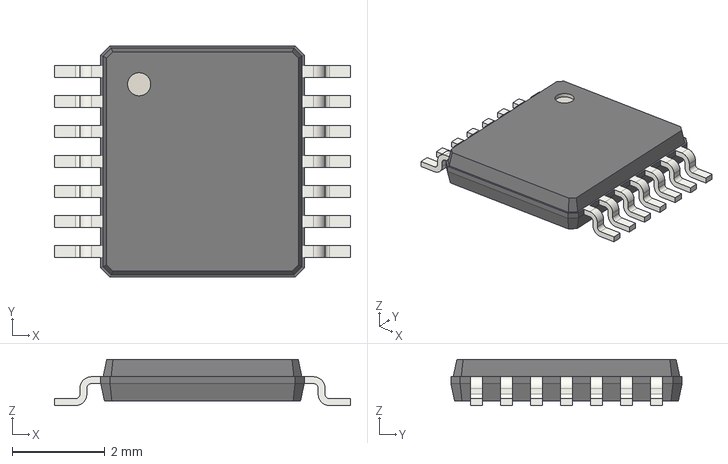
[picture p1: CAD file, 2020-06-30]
KiCAD/local_lib/TSSOP-14_4.4x5mm_P0.65mm.step
6.40 x 5.00 x 1 mm

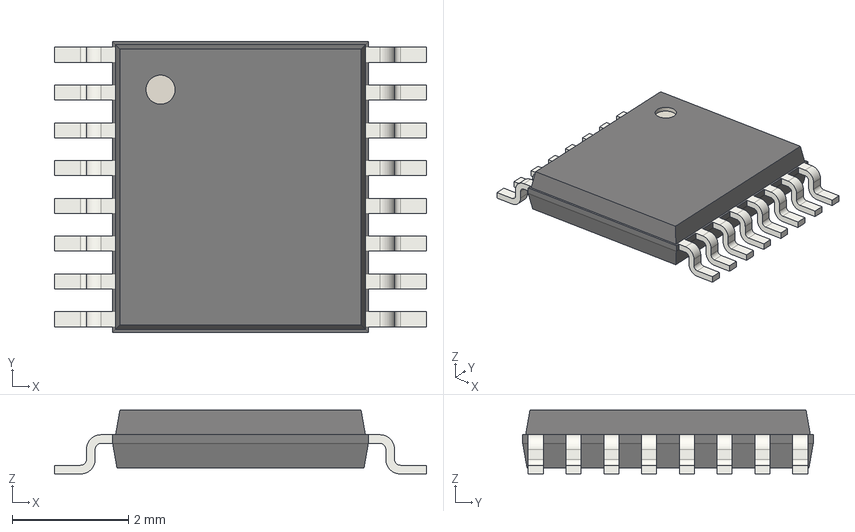
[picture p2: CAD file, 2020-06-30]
KiCAD/local_lib/TSSOP-16_4.4x5mm_P0.65mm.step
6.40 x 5.00 x 1.10 mm

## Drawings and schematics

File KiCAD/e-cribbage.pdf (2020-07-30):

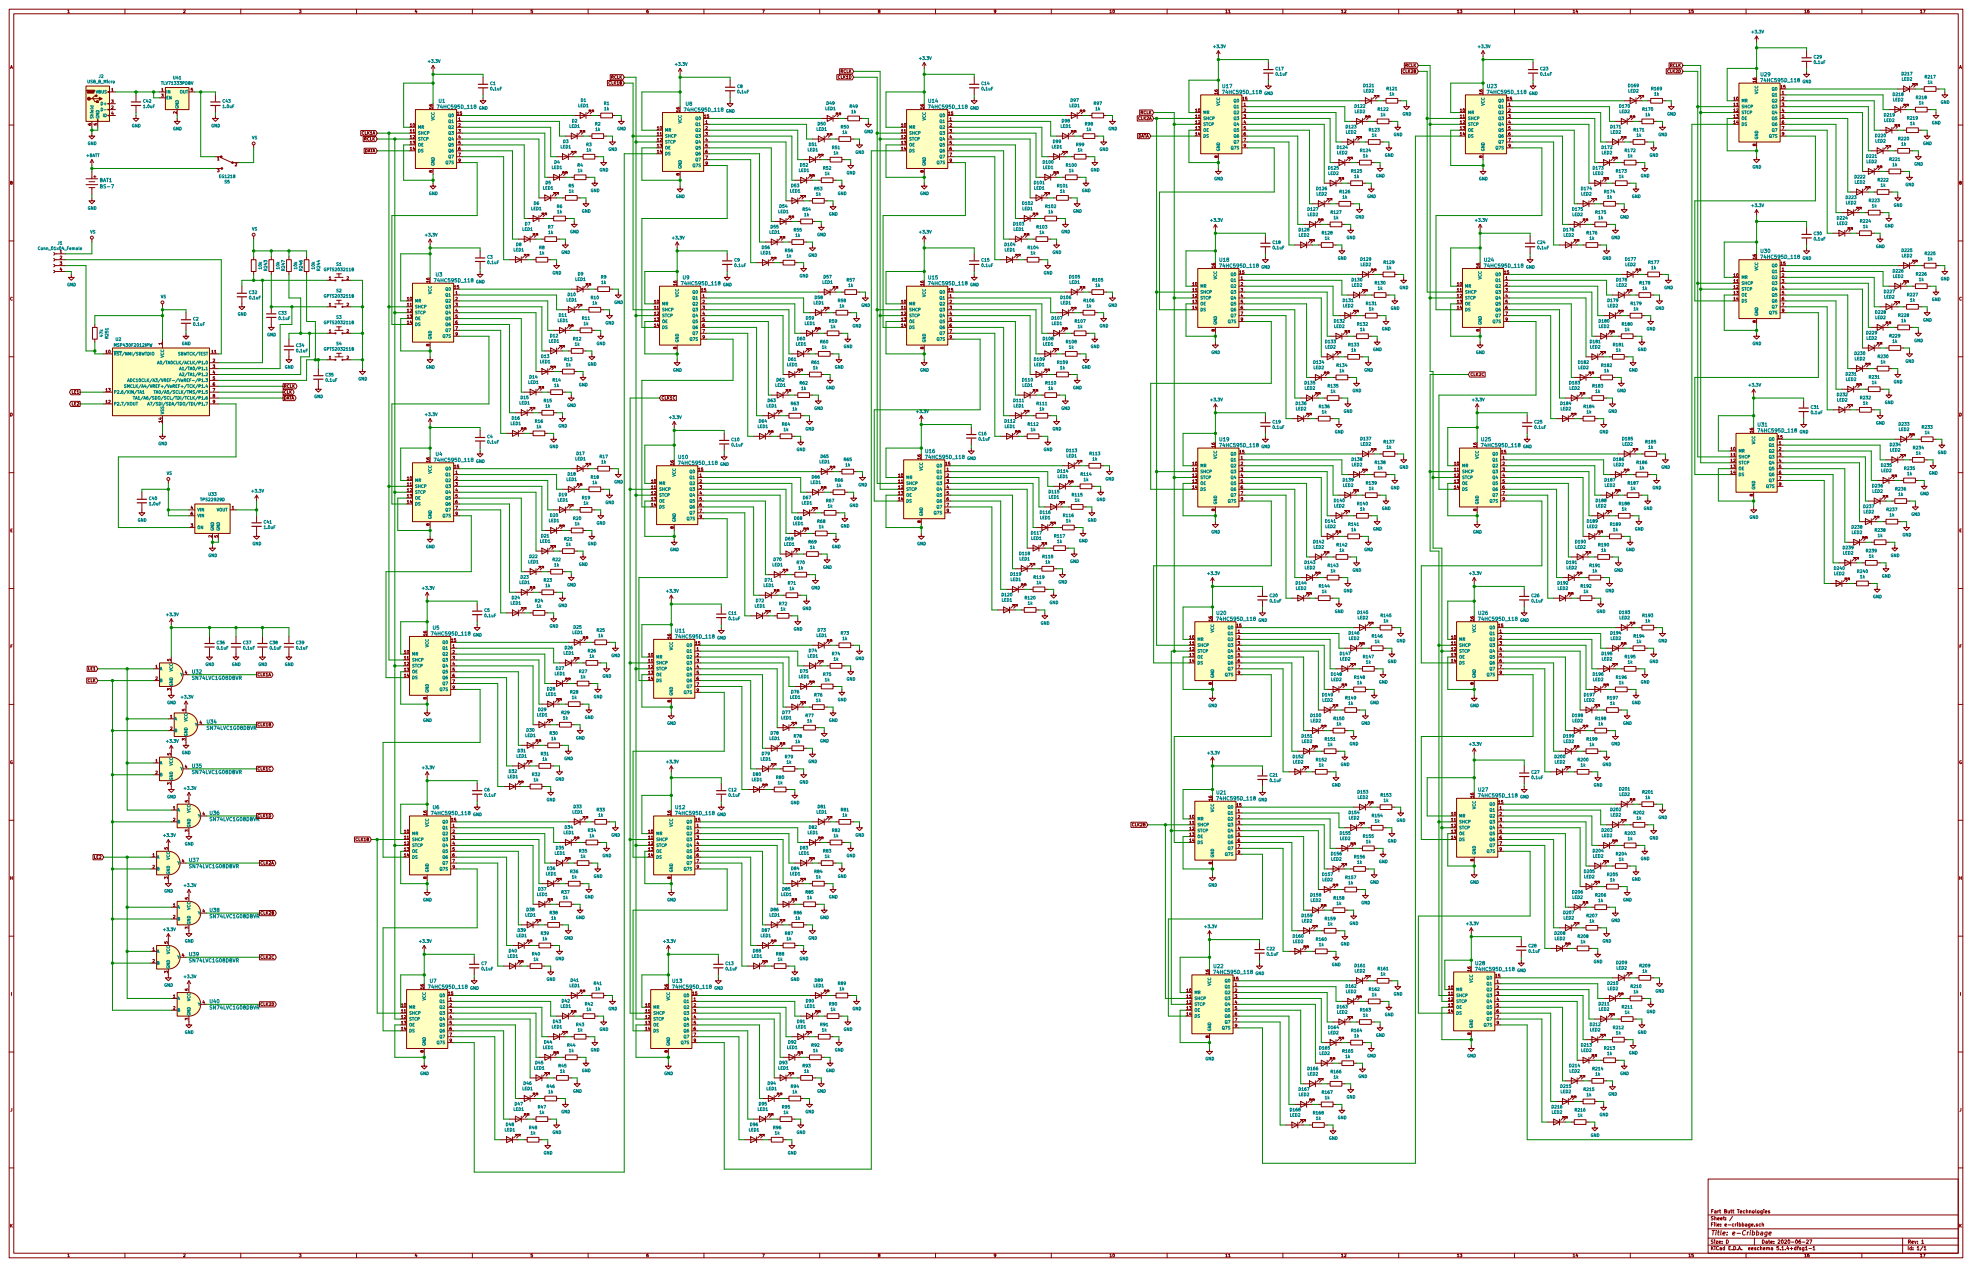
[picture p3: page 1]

1 RST/NMI/SBWTDIO 10 SBWTCK/TEST 11 P2.7/XOUT 12 P2.6/XIN/TA1 13 VSS 14 A0/TA0CLK/ACLK/P1.0 2 A1/TA0/P1.1 3 A2/TA1/P1.2 4 ADC10CLK/A3/VREF-/VeREF-/P1.3 5 SMCLK/A4/VREF+/VeREF+/TCK/P1.4 6 TA0/A5/SCLK/TMS/P1.5 7 TA1/A6/SDO/SCL/TDI/TCLK/P1.6 8 A7/SDI/SDA/TDO/TDI/P1.7 9 U2 MSP430F2012IPW

File: e-cribbage.sch Sheet: / Fart Butt Technologies

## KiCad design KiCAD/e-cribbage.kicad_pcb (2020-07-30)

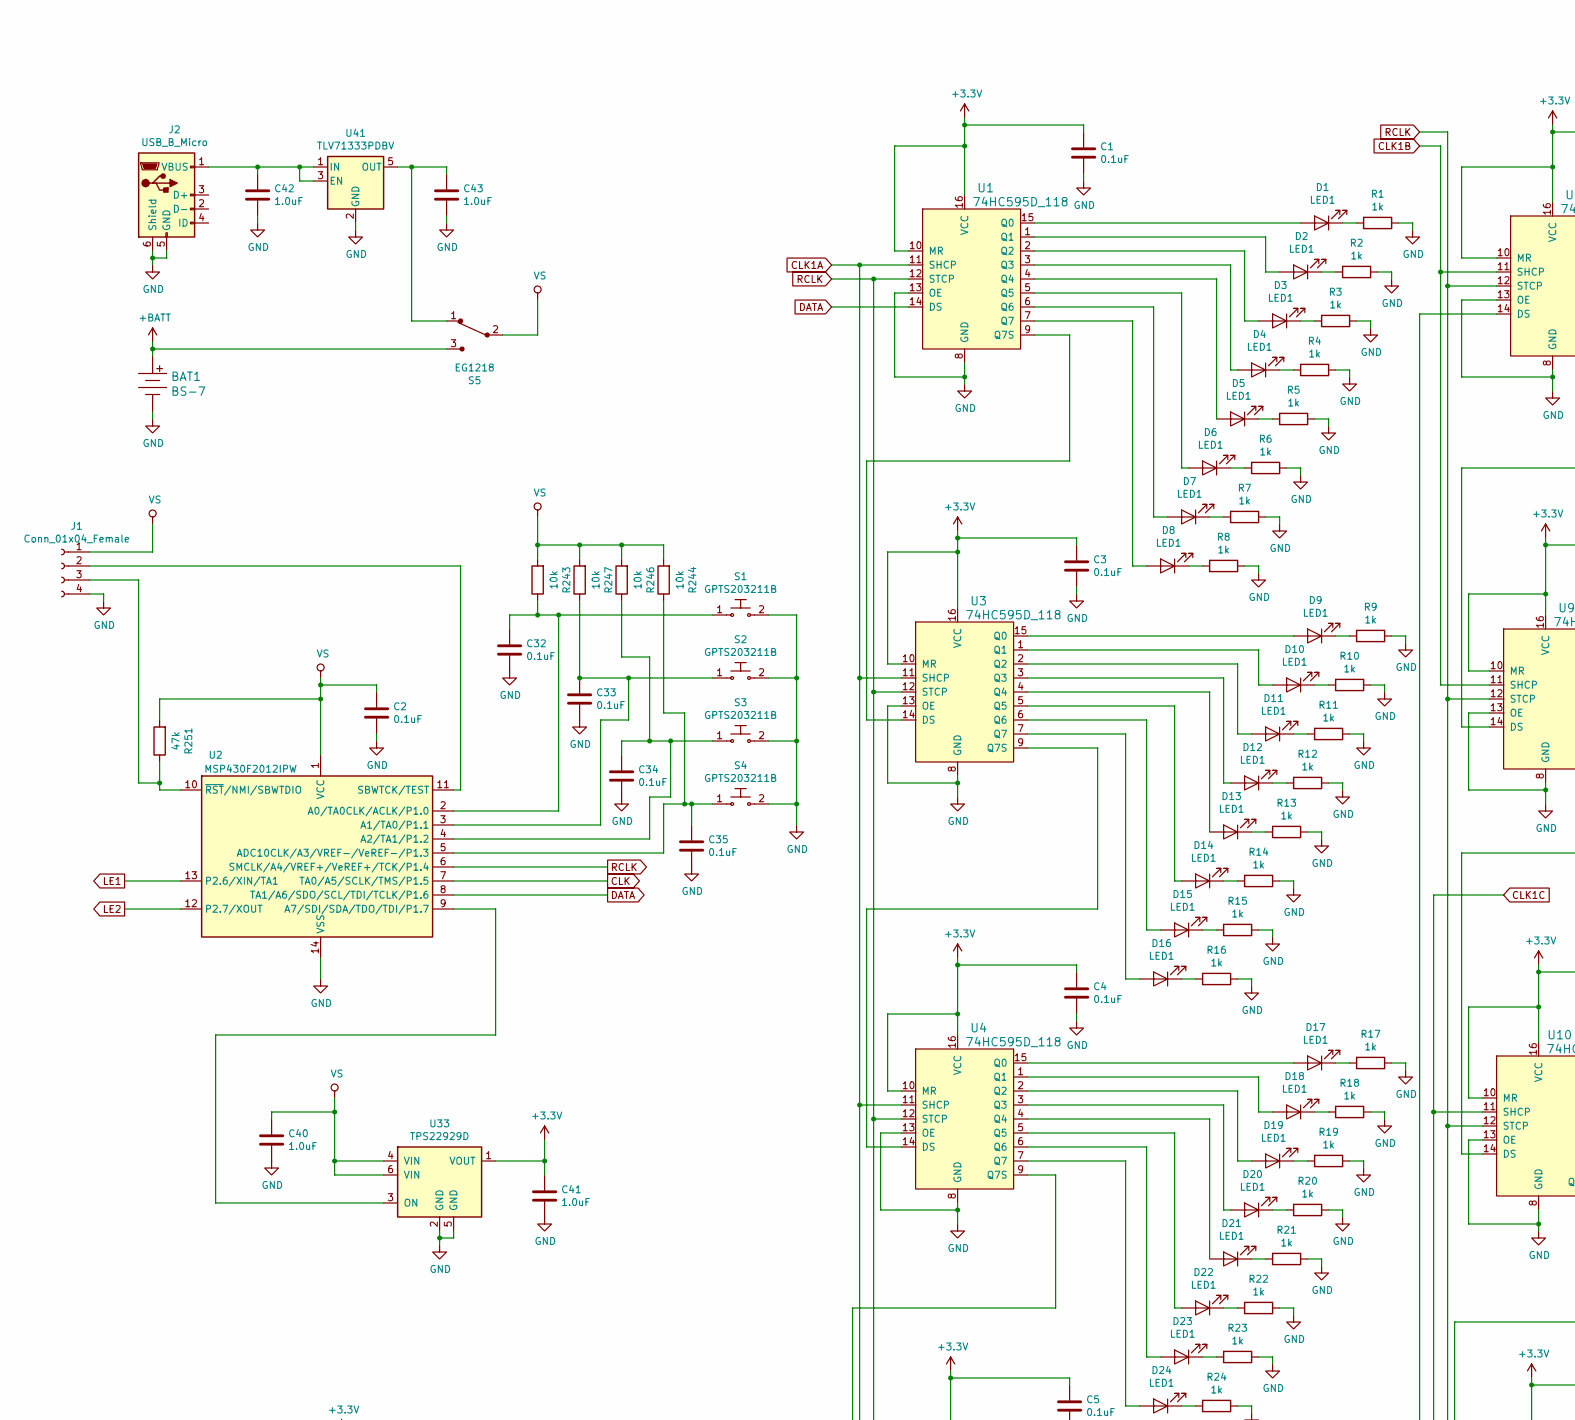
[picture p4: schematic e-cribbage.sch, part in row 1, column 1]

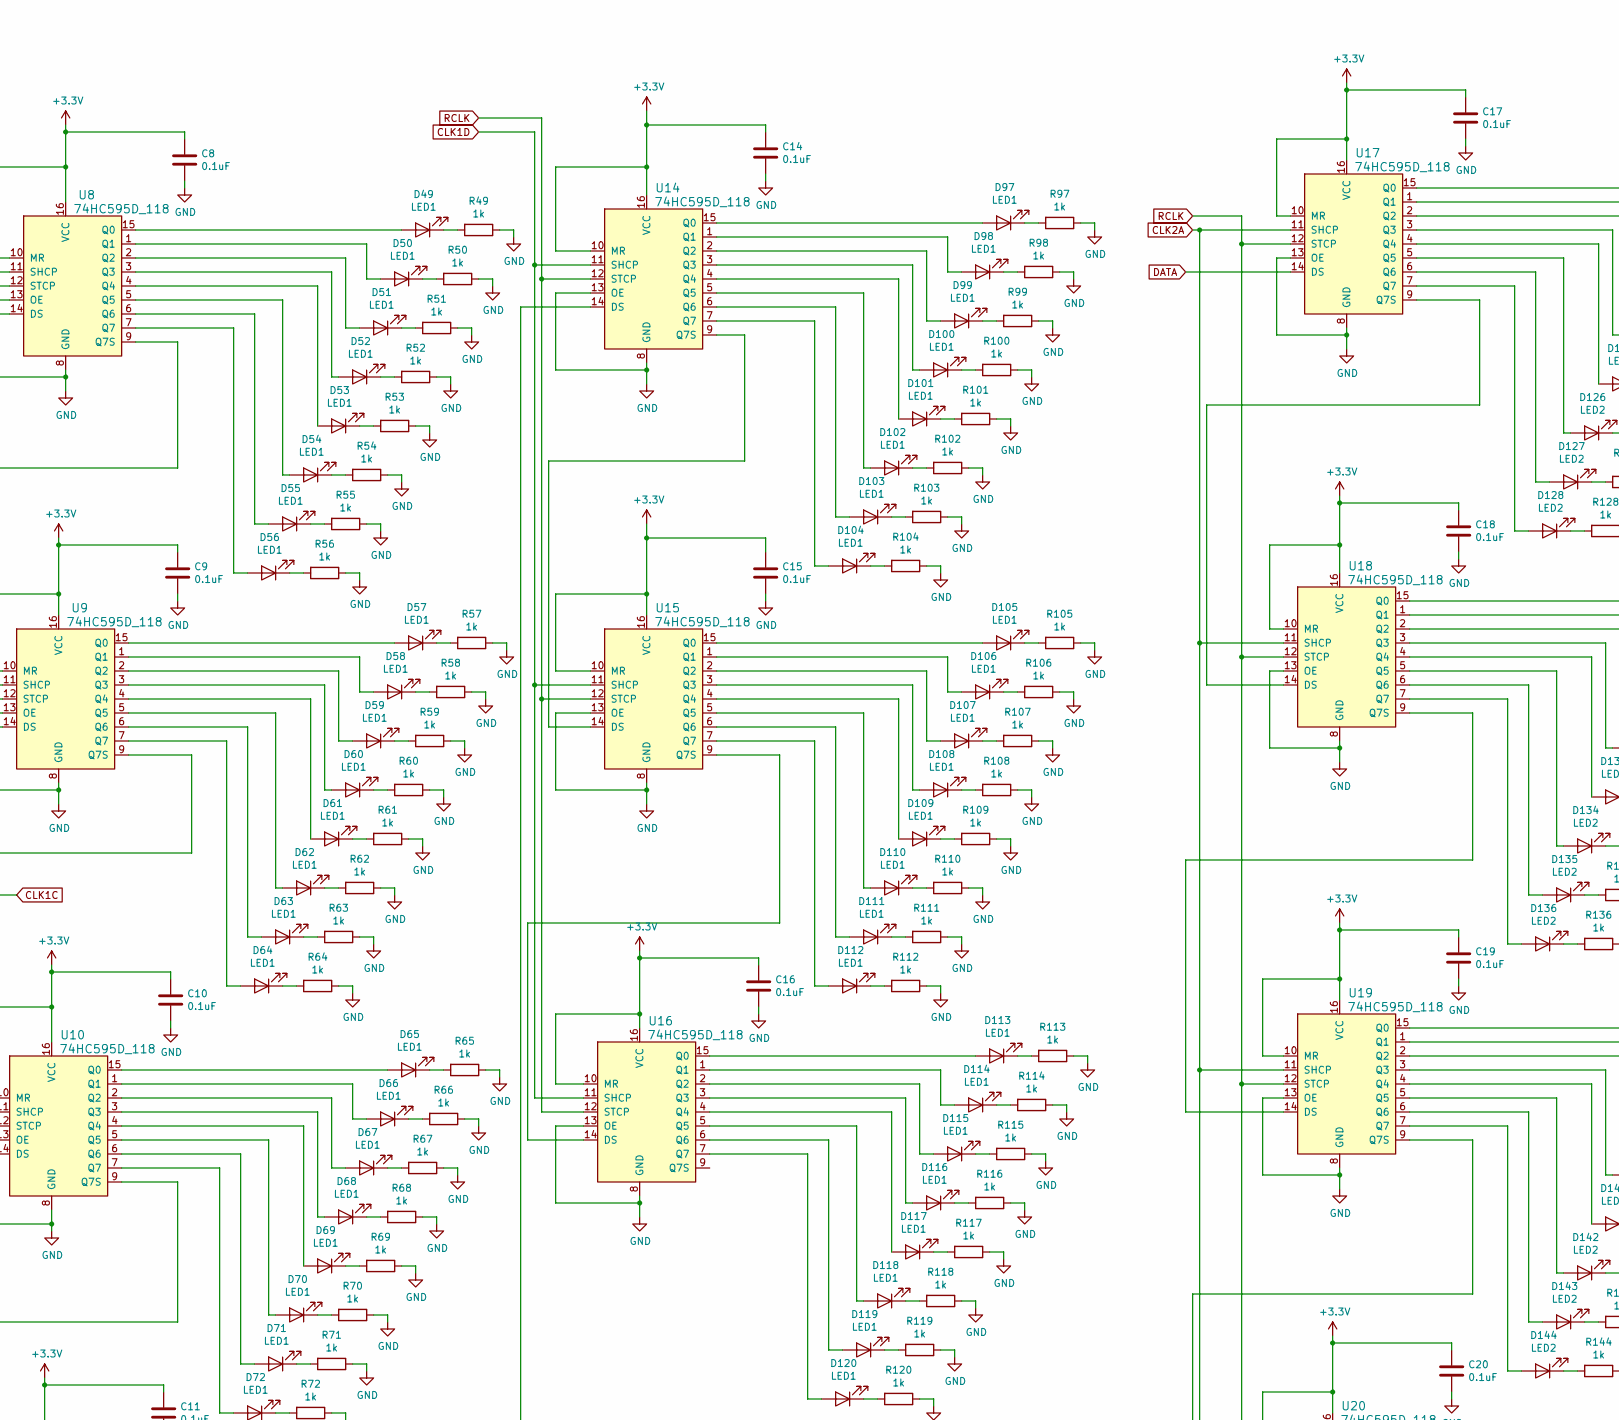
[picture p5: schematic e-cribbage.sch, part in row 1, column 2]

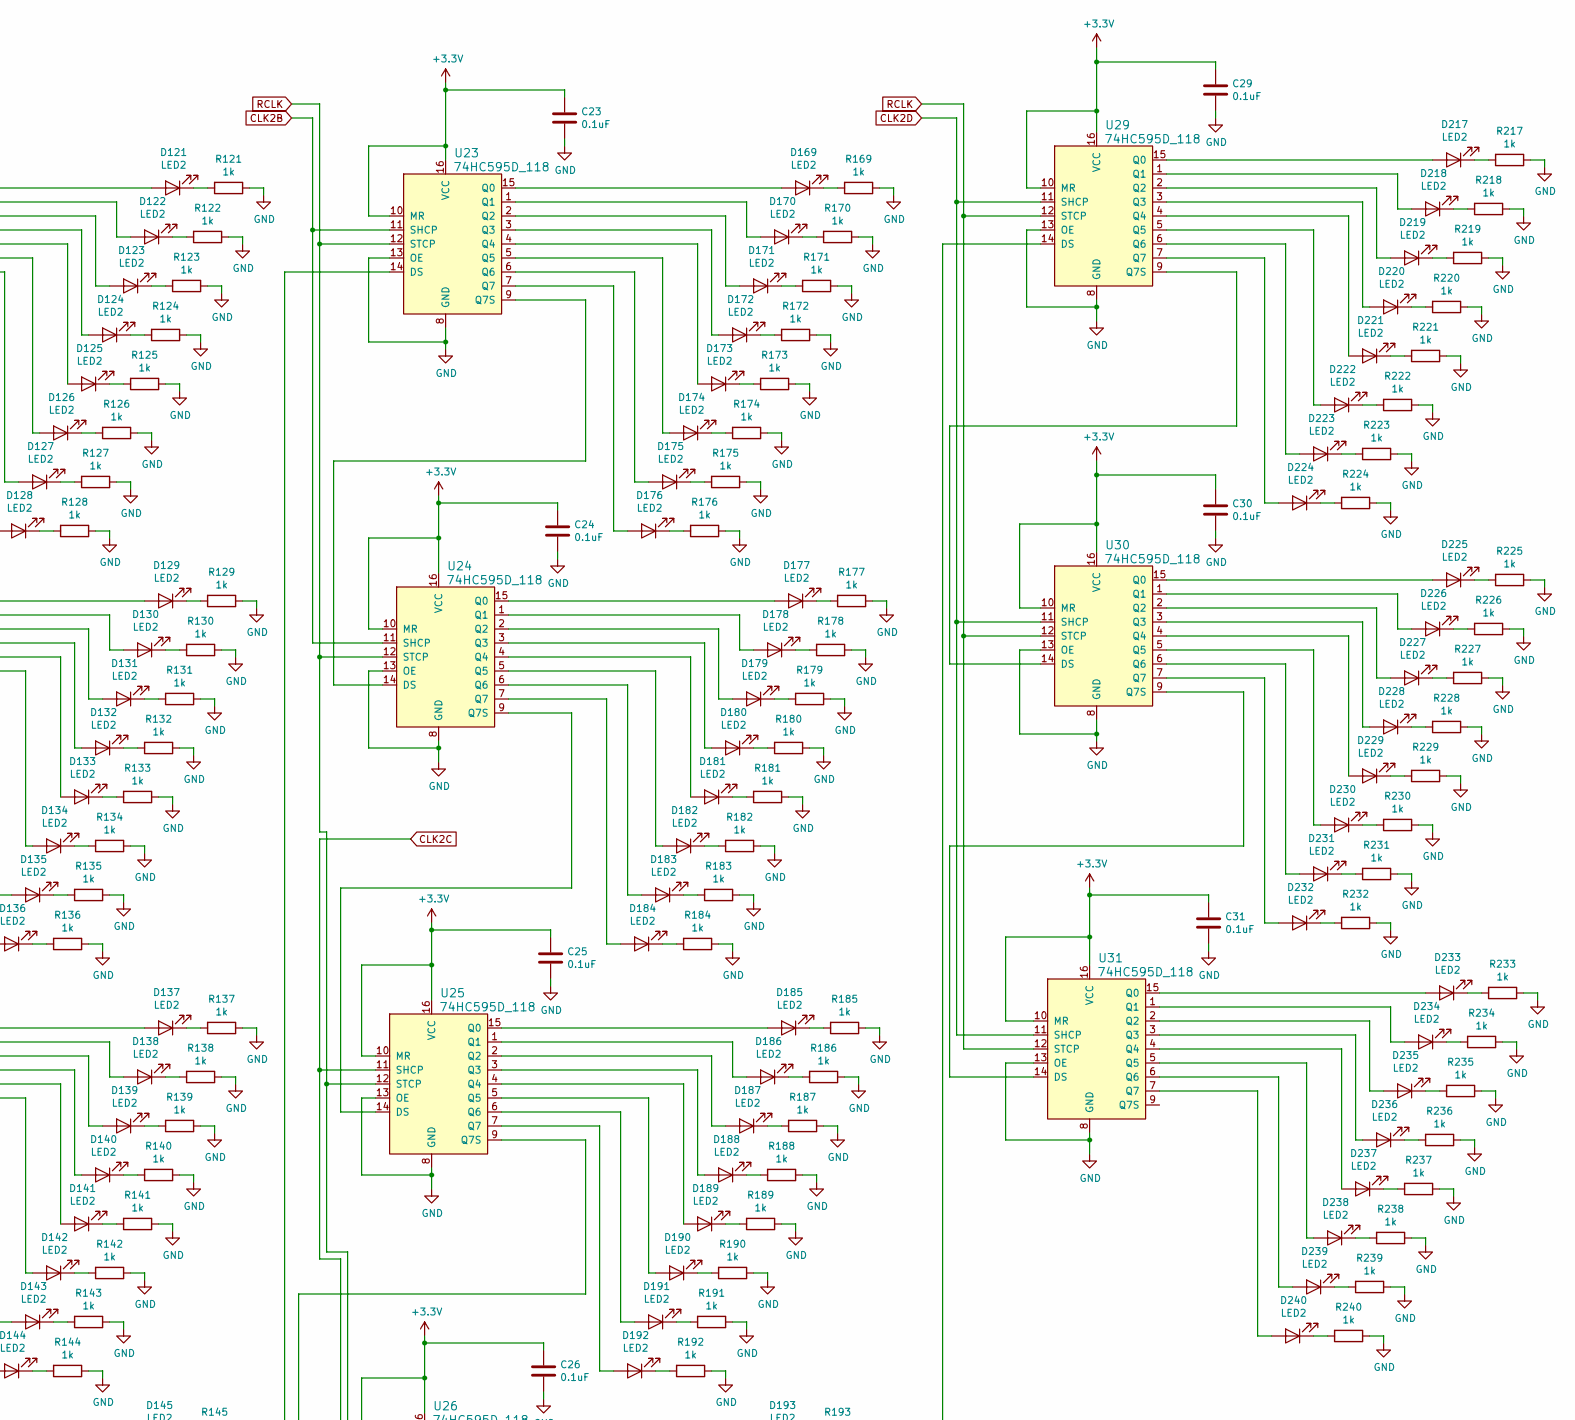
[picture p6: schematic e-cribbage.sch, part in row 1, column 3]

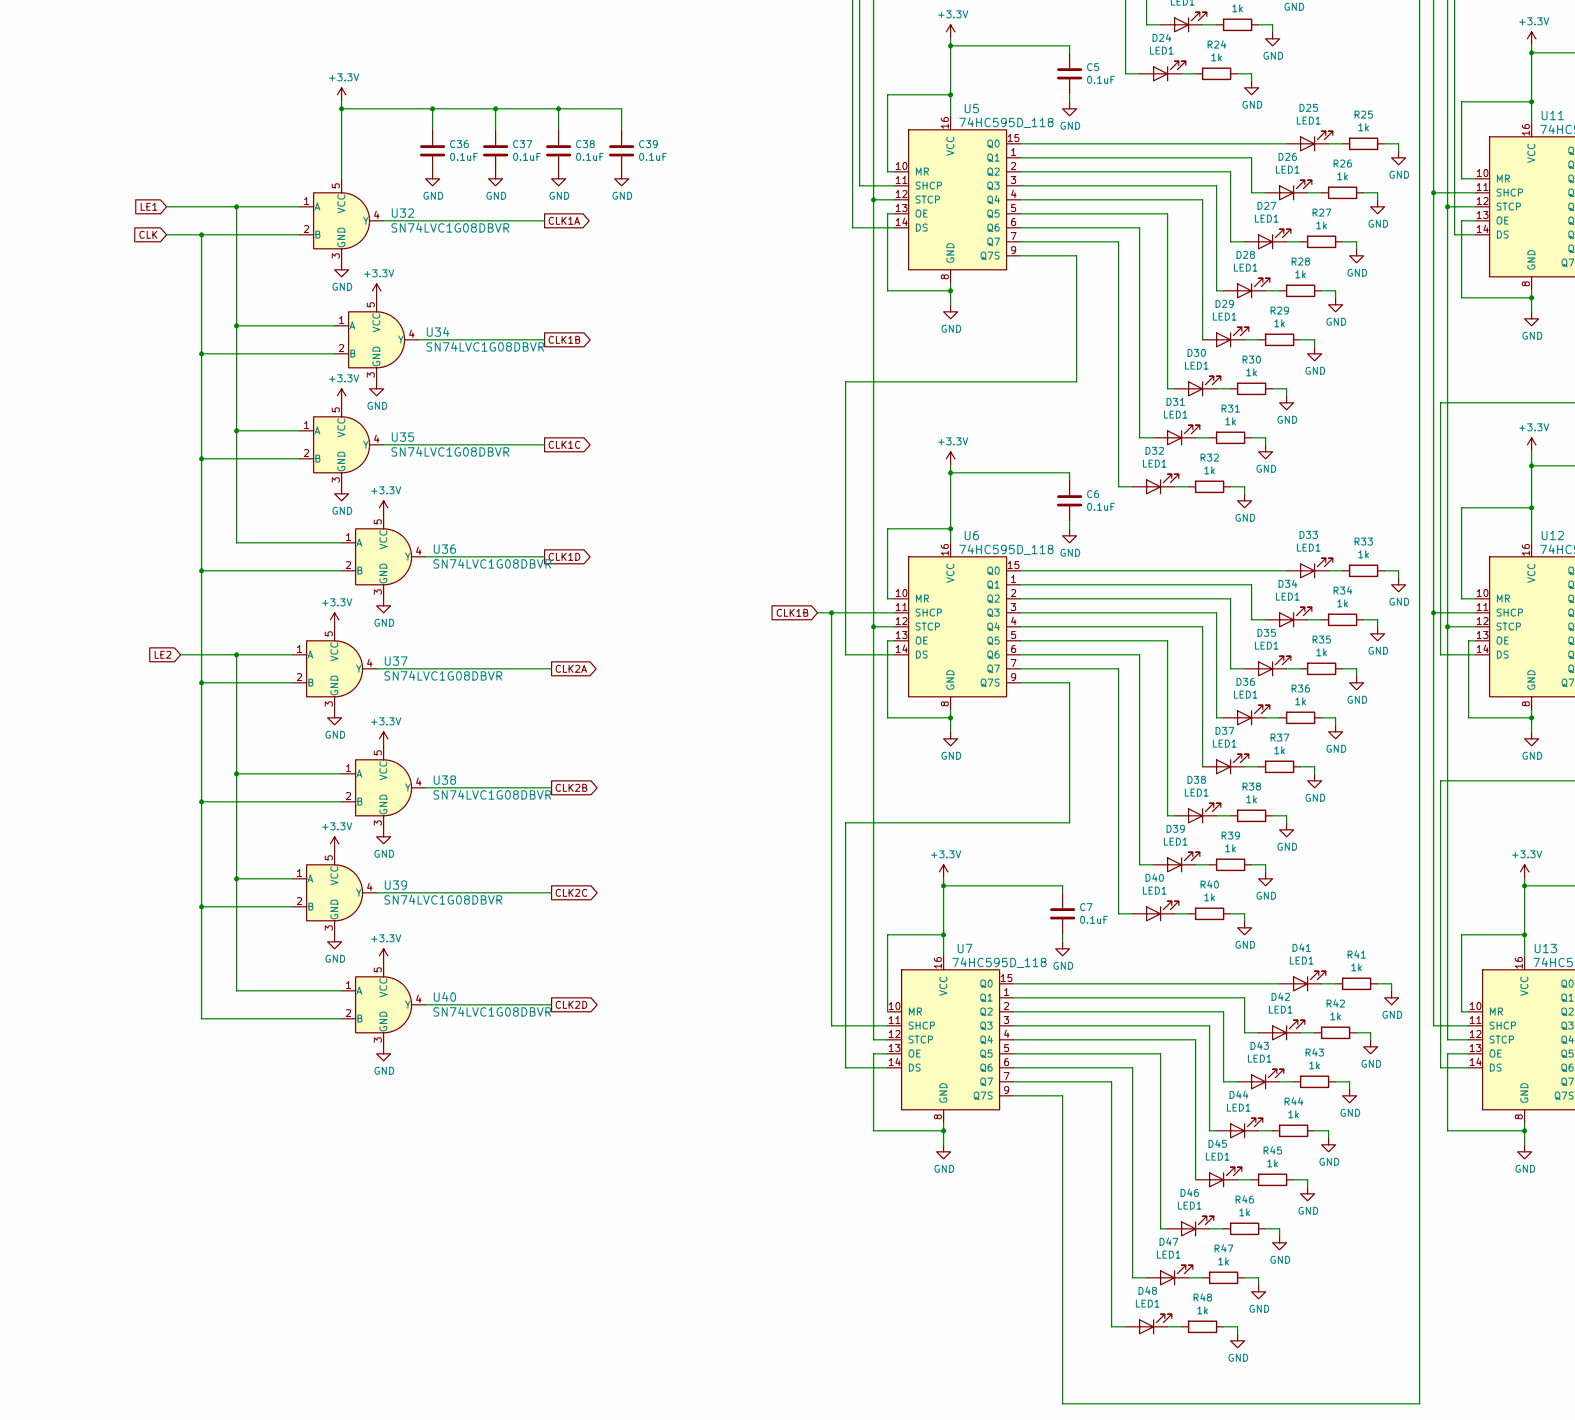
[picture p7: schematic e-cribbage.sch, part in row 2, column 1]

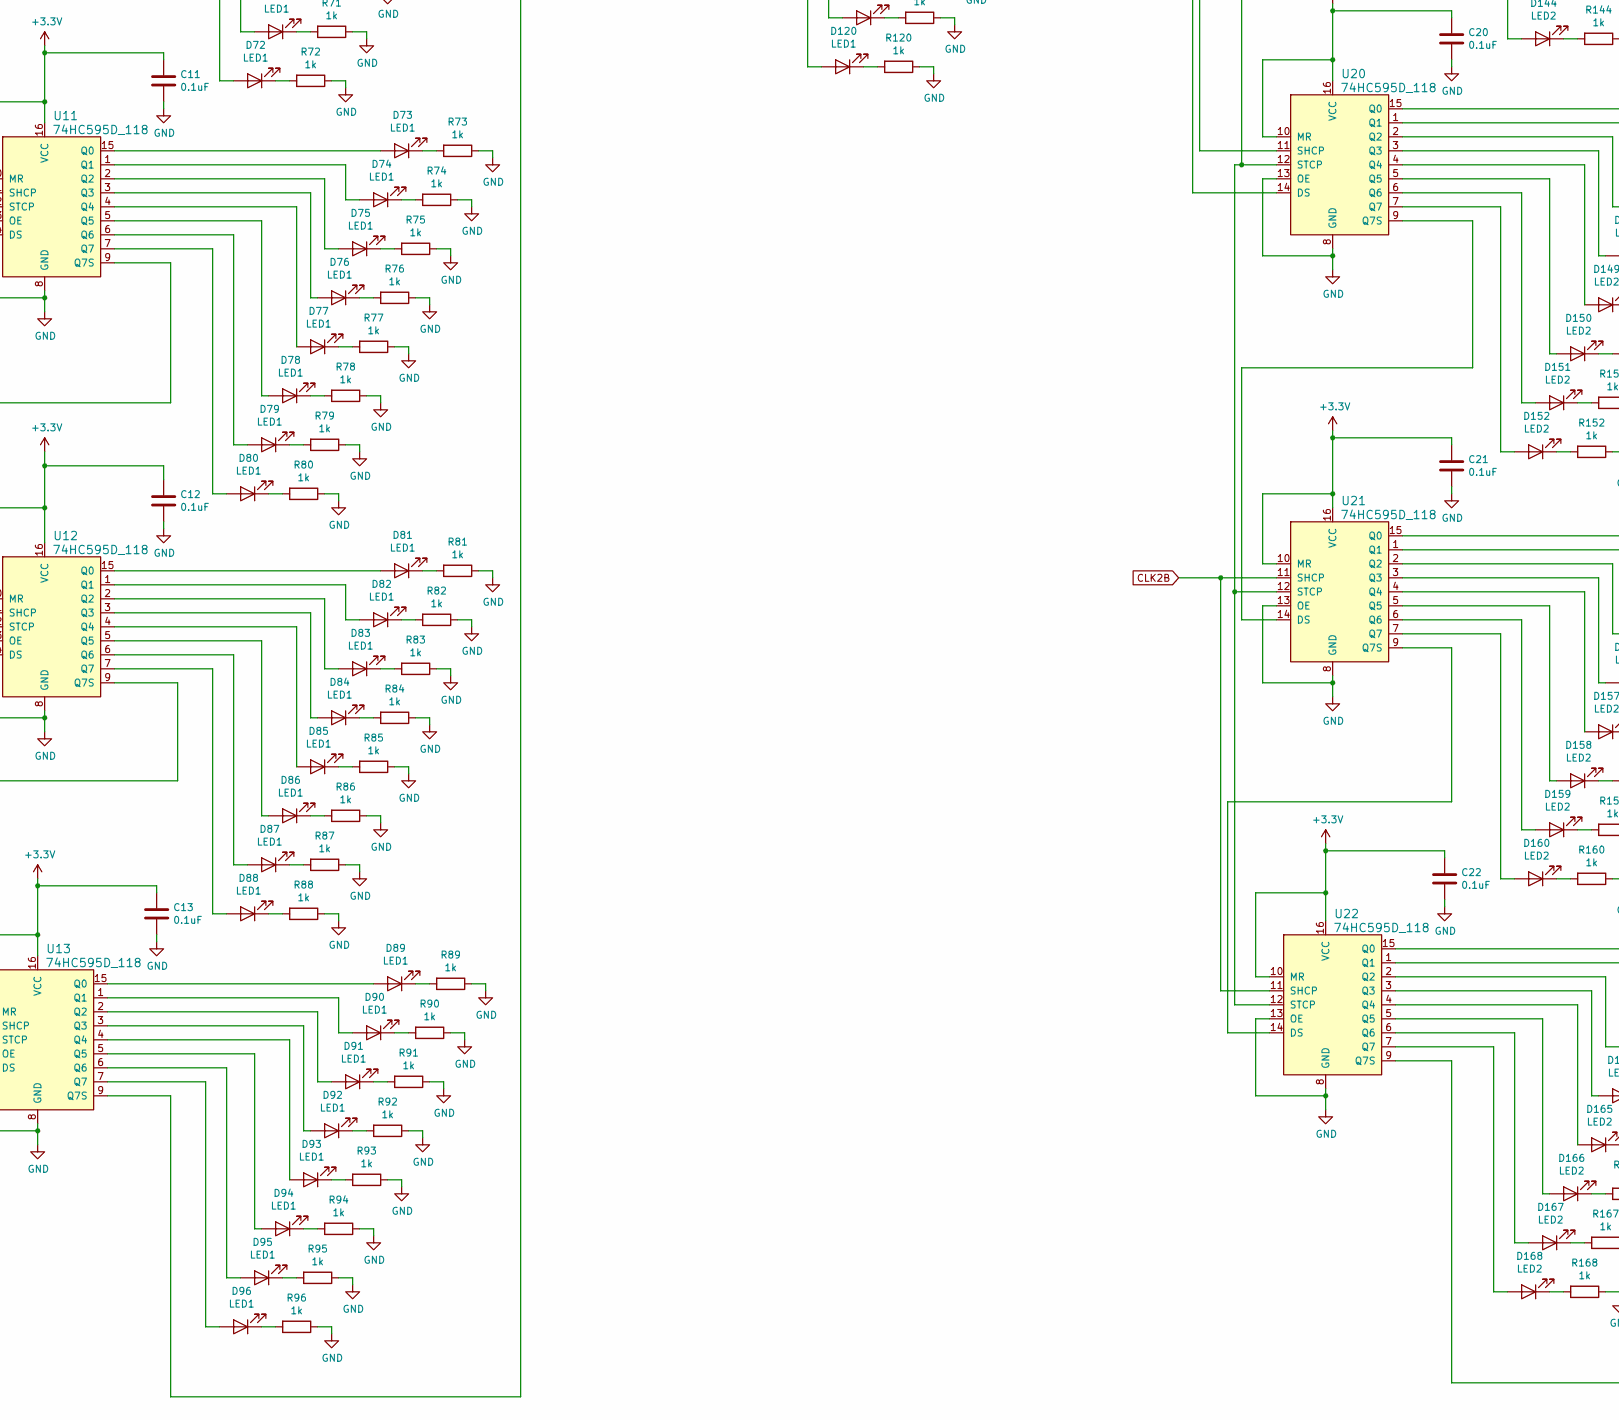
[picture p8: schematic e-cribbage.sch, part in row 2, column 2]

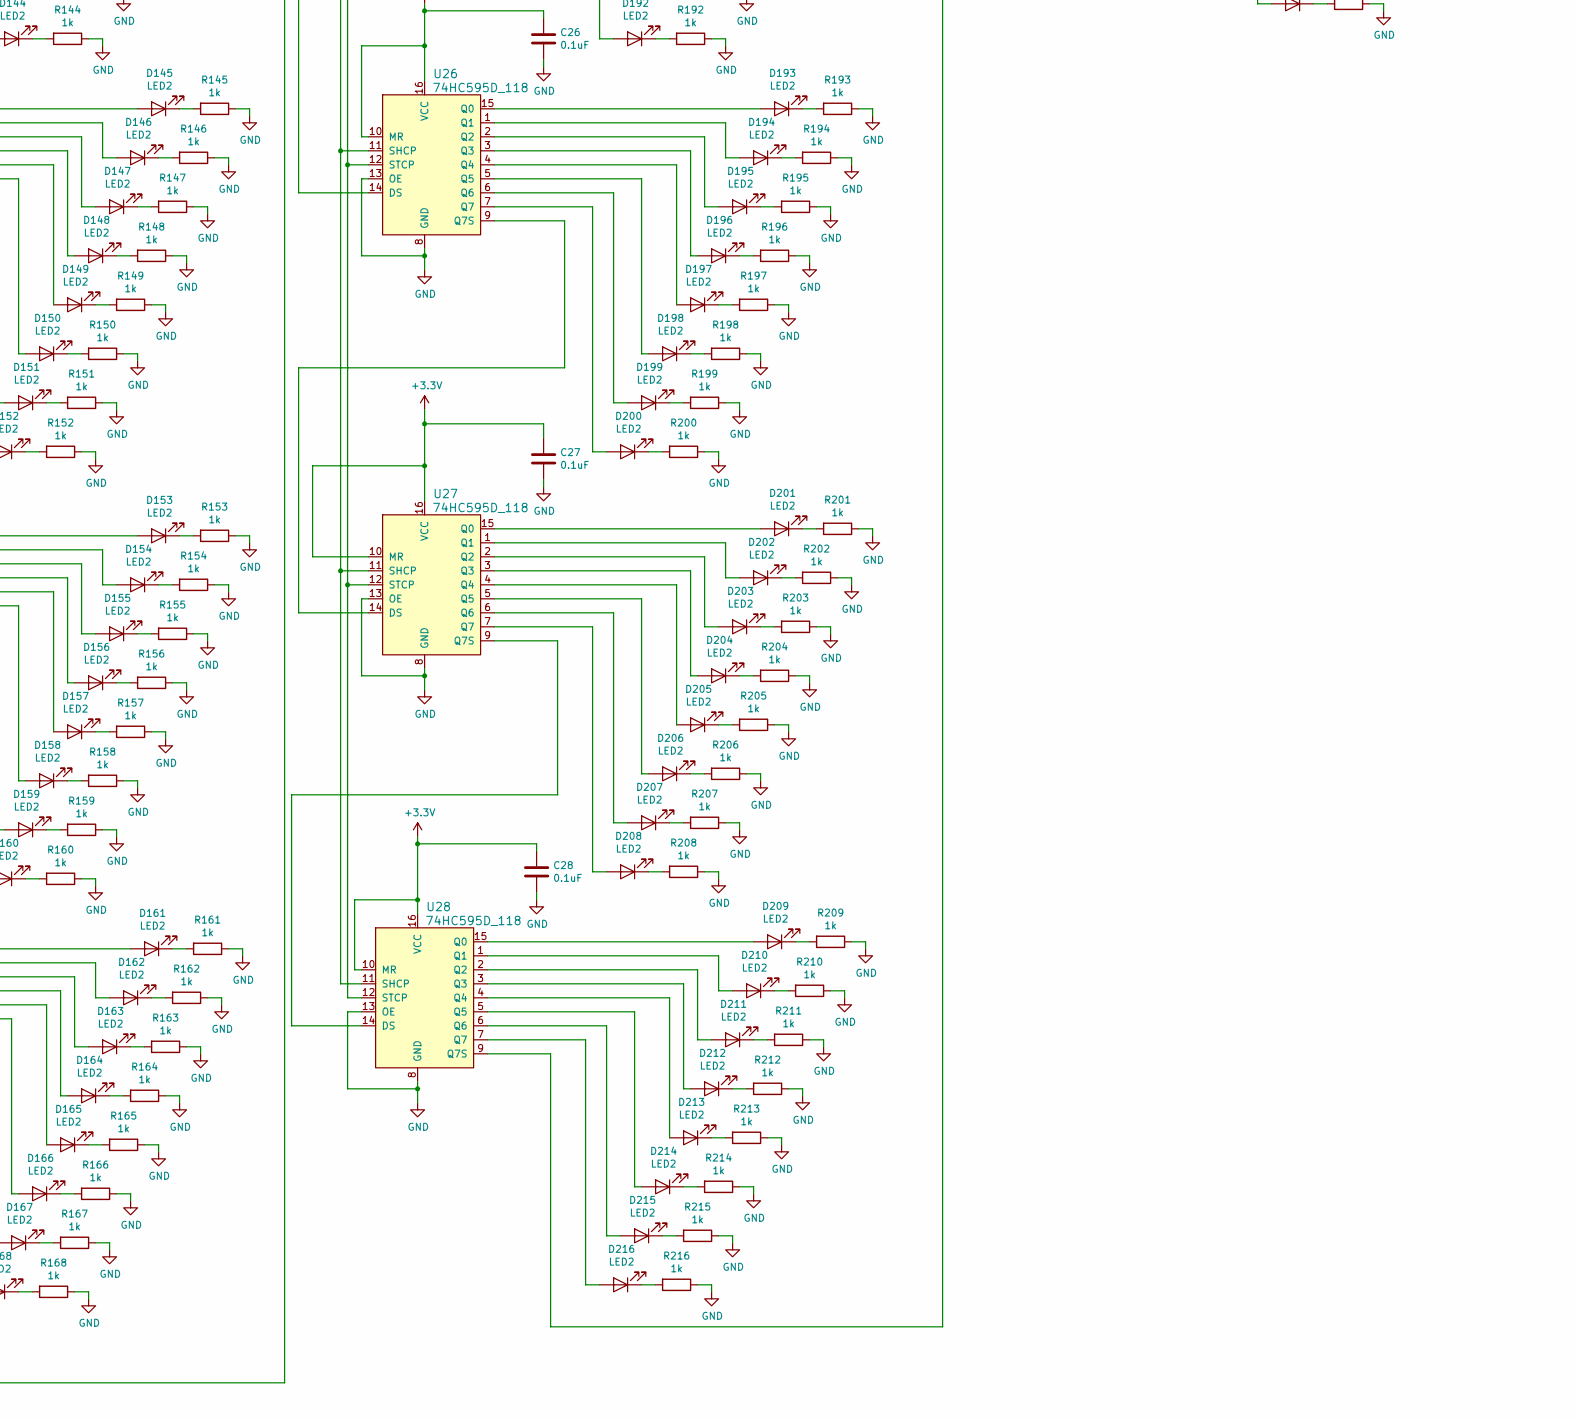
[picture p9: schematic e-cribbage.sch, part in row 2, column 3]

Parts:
BAT1: BS-7; Keystone_1058_1x2032-CoinCell; MPN BS-7; Digi-Key_PN BS-7-ND
C1, C2, C3, C4, C5, C6, C7, C8, C9, C10, C11, C12, C13, C14, C15, C16, C17, C18, C19, C20, C21, C22, C23, C24, C25, C26, C27, C28, C29, C30, C31, C32, C33, C34, C35, C36, C37, C38, C39: 0.1uF; C_0603_1608Metric_Pad1.05x0.95mm_HandSolder
C40, C41, C42, C43: 1.0uF; C_0603_1608Metric_Pad1.05x0.95mm_HandSolder
D1, D2, D3, D4, D5, D6, D7, D8, D9, D10, D11, D12, D13, D14, D15, D16, D17, D18, D19, D20, D21, D22, D23, D24, D25, D26, D27, D28, D29, D30, D31, D32, D33, D34, D35, D36, D37, D38, D39, D40, D41, D42, D43, D44, D45, D46, D47, D48, D49, D50, D51, D52, D53, D54, D55, D56, D57, D58, D59, D60, D61, D62, D63, D64, D65, D66, D67, D68, D69, D70, D71, D72, D73, D74, D75, D76, D77, D78, D79, D80, D81, D82, D83, D84, D85, D86, D87, D88, D89, D90, D91, D92, D93, D94, D95, D96, D97, D98, D99, D100, D101, D102, D103, D104, D105, D106, D107, D108, D109, D110, D111, D112, D113, D114, D115, D116, D117, D118, D119, D120: LED1; LED_0603
D121, D122, D123, D124, D125, D126, D127, D128, D129, D130, D131, D132, D133, D134, D135, D136, D137, D138, D139, D140, D141, D142, D143, D144, D145, D146, D147, D148, D149, D150, D151, D152, D153, D154, D155, D156, D157, D158, D159, D160, D161, D162, D163, D164, D165, D166, D167, D168, D169, D170, D171, D172, D173, D174, D175, D176, D177, D178, D179, D180, D181, D182, D183, D184, D185, D186, D187, D188, D189, D190, D191, D192, D193, D194, D195, D196, D197, D198, D199, D200, D201, D202, D203, D204, D205, D206, D207, D208, D209, D210, D211, D212, D213, D214, D215, D216, D217, D218, D219, D220, D221, D222, D223, D224, D225, D226, D227, D228, D229, D230, D231, D232, D233, D234, D235, D236, D237, D238, D239, D240: LED2; LED_0603
J1: Conn_01x04_Female; PinHeader_1x04_P1.27mm_Vertical
J2: USB_B_Micro; USB_Micro-B_Molex_47346-0001
R1, R2, R3, R4, R5, R6, R7, R8, R9, R10, R11, R12, R13, R14, R15, R16, R17, R18, R19, R20, R21, R22, R23, R24, R25, R26, R27, R28, R29, R30, R31, R32, R33, R34, R35, R36, R37, R38, R39, R40, R41, R42, R43, R44, R45, R46, R47, R48, R49, R50, R51, R52, R53, R54, R55, R56, R57, R58, R59, R60, R61, R62, R63, R64, R65, R66, R67, R68, R69, R70, R71, R72, R73, R74, R75, R76, R77, R78, R79, R80, R81, R82, R83, R84, R85, R86, R87, R88, R89, R90, R91, R92, R93, R94, R95, R96, R97, R98, R99, R100, R101, R102, R103, R104, R105, R106, R107, R108, R109, R110, R111, R112, R113, R114, R115, R116, R117, R118, R119, R120, R121, R122, R123, R124, R125, R126, R127, R128, R129, R130, R131, R132, R133, R134, R135, R136, R137, R138, R139, R140, R141, R142, R143, R144, R145, R146, R147, R148, R149, R150, R151, R152, R153, R154, R155, R156, R157, R158, R159, R160, R161, R162, R163, R164, R165, R166, R167, R168, R169, R170, R171, R172, R173, R174, R175, R176, R177, R178, R179, R180, R181, R182, R183, R184, R185, R186, R187, R188, R189, R190, R191, R192, R193, R194, R195, R196, R197, R198, R199, R200, R201, R202, R203, R204, R205, R206, R207, R208, R209, R210, R211, R212, R213, R214, R215, R216, R217, R218, R219, R220, R221, R222, R223, R224, R225, R226, R227, R228, R229, R230, R231, R232, R233, R234, R235, R236, R237, R238, R239, R240: 1k; R_0603
R243, R244, R246, R247: 10k; R_0603
R251: 47k; R_0603
S1, S2, S3, S4: GPTS203211B; KS12R22; MPN GPTS203211B; Digi-Key_PN CW181-ND
S5: EG1218; SW_SPDT_CK-JS102011SAQN; MPN EG1218; Digi-Key_PN EG1903-ND
U1, U3, U4, U5, U6, U7, U8, U9, U10, U11, U12, U13, U14, U15, U16, U17, U18, U19, U20, U21, U22, U23, U24, U25, U26, U27, U28, U29, U30, U31: 74HC595D_118; TSSOP-16_W4.40mm; MPN 74HC595D,118; Digi-Key_PN 1727-2821-1-ND
U2: MSP430F2012IPW; TSSOP-14_W4.4mm
U32, U34, U35, U36, U37, U38, U39, U40: SN74LVC1G08DBVR; SOT-753; MPN SN74LVC1G08DBVR; Digi-Key_PN 296-11601-1-ND
U33: TPS22929D; SOT-23-6
U41: TLV71333PDBV; SOT-23-5

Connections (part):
+3V3: C1.1, C3.1, C4.1, C5.1, C6.1, C7.1, C8.1, C9.1, C10.1, C11.1, C12.1, C13.1, C14.1, C15.1, C16.1, C17.1, C18.1, C19.1, C20.1, C21.1, C22.1, C23.1, C24.1, C25.1, C26.1, C27.1, C28.1, C29.1, C30.1, C31.1, C36.1, C37.1, C38.1, C39.1, C41.1, U1.10 (MR), U1.16 (VCC), U3.10 (MR), U3.16 (VCC), U4.10 (MR), U4.16 (VCC), U5.10 (MR), U5.16 (VCC), U6.10 (MR), U6.16 (VCC), U7.10 (MR), U7.16 (VCC), U8.10 (MR), U8.16 (VCC), U9.10 (MR), U9.16 (VCC), U10.10 (MR), U10.16 (VCC), U11.10 (MR), U11.16 (VCC), U12.10 (MR), U12.16 (VCC), U13.10 (MR), U13.16 (VCC), U14.10 (MR), U14.16 (VCC), U15.10 (MR), U15.16 (VCC), U16.10 (MR), U16.16 (VCC), U17.10 (MR), U17.16 (VCC), U18.10 (MR), U18.16 (VCC), U19.10 (MR), U19.16 (VCC), U20.10 (MR), U20.16 (VCC), U21.10 (MR), U21.16 (VCC), U22.10 (MR), U22.16 (VCC), U23.10 (MR), U23.16 (VCC), U24.10 (MR)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
+BATT: BAT1.1, S5.3
CLK: U2.7 (TA0/A5/SCLK/TMS/P1.5), U32.2 (B), U34.2 (B), U35.2 (B), U36.2 (B), U37.2 (B), U38.2 (B), U39.2 (B), U40.2 (B)
CLK1A: U1.11 (SHCP), U3.11 (SHCP), U4.11 (SHCP), U5.11 (SHCP), U32.4 (Y)
CLK1B: U6.11 (SHCP), U7.11 (SHCP), U8.11 (SHCP), U9.11 (SHCP), U34.4 (Y)
CLK1C: U10.11 (SHCP), U11.11 (SHCP), U12.11 (SHCP), U13.11 (SHCP), U35.4 (Y)
CLK1D: U14.11 (SHCP), U15.11 (SHCP), U16.11 (SHCP), U36.4 (Y)
CLK2A: U17.11 (SHCP), U18.11 (SHCP), U19.11 (SHCP), U20.11 (SHCP), U37.4 (Y)
CLK2B: U21.11 (SHCP), U22.11 (SHCP), U23.11 (SHCP), U24.11 (SHCP), U38.4 (Y)
CLK2C: U25.11 (SHCP), U26.11 (SHCP), U27.11 (SHCP), U28.11 (SHCP), U39.4 (Y)
CLK2D: U29.11 (SHCP), U30.11 (SHCP), U31.11 (SHCP), U40.4 (Y)
DATA: U1.14 (DS), U2.8 (TA1/A6/SDO/SCL/TDI/TCLK/P1.6), U17.14 (DS)
GND: BAT1.2, C1.2, C2.2, C3.2, C4.2, C5.2, C6.2, C7.2, C8.2, C9.2, C10.2, C11.2, C12.2, C13.2, C14.2, C15.2, C16.2, C17.2, C18.2, C19.2, C20.2, C21.2, C22.2, C23.2, C24.2, C25.2, C26.2, C27.2, C28.2, C29.2, C30.2, C31.2, C32.2, C33.2, C34.2, C35.2, C36.2, C37.2, C38.2, C39.2, C40.2, C41.2, C42.2, C43.2, J1.4, J2.5 (GND), J2.6 (Shield), R1.1, R2.1, R3.1, R4.1, R5.1, R6.1, R7.1, R8.1, R9.1, R10.1, R11.1, R12.1, R13.1, R14.1, R15.1, R16.1, R17.1, R18.1, R19.1, R20.1, R21.1, R22.1, R23.1, R24.1, R25.1, R26.1, R27.1, R28.1, R29.1, R30.1, R31.1, R32.1, R33.1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
LE1: U2.13 (P2.6/XIN/TA1), U32.1 (A), U34.1 (A), U35.1 (A), U36.1 (A)
LE2: U2.12 (P2.7/XOUT), U37.1 (A), U38.1 (A), U39.1 (A), U40.1 (A)
unnamed: C32.1, R243.1, S1.1, U2.2 (A0/TA0CLK/ACLK/P1.0)
unnamed: C33.1, R247.1, S2.1, U2.3 (A1/TA0/P1.1)
unnamed: C34.1, R246.1, S3.1, U2.4 (A2/TA1/P1.2)
unnamed: C35.1, R244.1, S4.1, U2.5 (ADC10CLK/A3/VREF-/VeREF-/P1.3)
unnamed: C42.1, J2.1 (VBUS), U41.1 (IN), U41.3 (EN)
unnamed: C43.1, S5.1, U41.5 (OUT)
unnamed: D1.1 (K), R1.2
unnamed: D1.2 (A), U1.15 (Q0)
unnamed: D2.1 (K), R2.2
unnamed: D2.2 (A), U1.1 (Q1)
unnamed: D3.1 (K), R3.2
unnamed: D3.2 (A), U1.2 (Q2)
unnamed: D4.1 (K), R4.2
unnamed: D4.2 (A), U1.3 (Q3)
unnamed: D5.1 (K), R5.2
unnamed: D5.2 (A), U1.4 (Q4)
unnamed: D6.1 (K), R6.2
unnamed: D6.2 (A), U1.5 (Q5)
unnamed: D7.1 (K), R7.2
unnamed: D7.2 (A), U1.6 (Q6)
unnamed: D8.1 (K), R8.2
unnamed: D8.2 (A), U1.7 (Q7)
unnamed: D9.1 (K), R9.2
unnamed: D9.2 (A), U3.15 (Q0)
unnamed: D10.1 (K), R10.2
unnamed: D10.2 (A), U3.1 (Q1)
unnamed: D11.1 (K), R11.2
unnamed: D11.2 (A), U3.2 (Q2)
unnamed: D12.1 (K), R12.2
unnamed: D12.2 (A), U3.3 (Q3)
unnamed: D13.1 (K), R13.2
unnamed: D13.2 (A), U3.4 (Q4)
unnamed: D14.1 (K), R14.2
unnamed: D14.2 (A), U3.5 (Q5)
unnamed: D15.1 (K), R15.2
unnamed: D15.2 (A), U3.6 (Q6)
unnamed: D16.1 (K), R16.2
unnamed: D16.2 (A), U3.7 (Q7)
unnamed: D17.1 (K), R17.2
unnamed: D17.2 (A), U4.15 (Q0)
unnamed: D18.1 (K), R18.2
unnamed: D18.2 (A), U4.1 (Q1)
unnamed: D19.1 (K), R19.2
unnamed: D19.2 (A), U4.2 (Q2)
unnamed: D20.1 (K), R20.2
unnamed: D20.2 (A), U4.3 (Q3)
unnamed: D21.1 (K), R21.2
unnamed: D21.2 (A), U4.4 (Q4)
unnamed: D22.1 (K), R22.2
unnamed: D22.2 (A), U4.5 (Q5)
unnamed: D23.1 (K), R23.2
unnamed: D23.2 (A), U4.6 (Q6)
unnamed: D24.1 (K), R24.2
unnamed: D24.2 (A), U4.7 (Q7)
unnamed: D25.1 (K), R25.2
unnamed: D25.2 (A), U5.15 (Q0)
unnamed: D26.1 (K), R26.2
unnamed: D26.2 (A), U5.1 (Q1)
unnamed: D27.1 (K), R27.2
unnamed: D27.2 (A), U5.2 (Q2)
unnamed: D28.1 (K), R28.2
unnamed: D28.2 (A), U5.3 (Q3)
unnamed: D29.1 (K), R29.2
unnamed: D29.2 (A), U5.4 (Q4)
unnamed: D30.1 (K), R30.2
unnamed: D30.2 (A), U5.5 (Q5)
unnamed: D31.1 (K), R31.2
unnamed: D31.2 (A), U5.6 (Q6)
unnamed: D32.1 (K), R32.2
unnamed: D32.2 (A), U5.7 (Q7)
unnamed: D33.1 (K), R33.2
unnamed: D33.2 (A), U6.15 (Q0)
unnamed: D34.1 (K), R34.2
unnamed: D34.2 (A), U6.1 (Q1)
unnamed: D35.1 (K), R35.2
unnamed: D35.2 (A), U6.2 (Q2)
unnamed: D36.1 (K), R36.2
unnamed: D36.2 (A), U6.3 (Q3)
unnamed: D37.1 (K), R37.2
unnamed: D37.2 (A), U6.4 (Q4)
unnamed: D38.1 (K), R38.2
unnamed: D38.2 (A), U6.5 (Q5)
unnamed: D39.1 (K), R39.2
unnamed: D39.2 (A), U6.6 (Q6)
unnamed: D40.1 (K), R40.2
unnamed: D40.2 (A), U6.7 (Q7)
unnamed: D41.1 (K), R41.2
unnamed: D41.2 (A), U7.15 (Q0)
unnamed: D42.1 (K), R42.2
unnamed: D42.2 (A), U7.1 (Q1)
unnamed: D43.1 (K), R43.2
unnamed: D43.2 (A), U7.2 (Q2)
unnamed: D44.1 (K), R44.2
unnamed: D44.2 (A), U7.3 (Q3)
unnamed: D45.1 (K), R45.2
unnamed: D45.2 (A), U7.4 (Q4)
unnamed: D46.1 (K), R46.2
unnamed: D46.2 (A), U7.5 (Q5)
unnamed: D47.1 (K), R47.2
unnamed: D47.2 (A), U7.6 (Q6)
unnamed: D48.1 (K), R48.2
unnamed: D48.2 (A), U7.7 (Q7)
unnamed: D49.1 (K), R49.2
unnamed: D49.2 (A), U8.15 (Q0)
unnamed: D50.1 (K), R50.2
unnamed: D50.2 (A), U8.1 (Q1)
unnamed: D51.1 (K), R51.2
unnamed: D51.2 (A), U8.2 (Q2)
unnamed: D52.1 (K), R52.2
unnamed: D52.2 (A), U8.3 (Q3)
unnamed: D53.1 (K), R53.2
unnamed: D53.2 (A), U8.4 (Q4)
unnamed: D54.1 (K), R54.2
unnamed: D54.2 (A), U8.5 (Q5)
unnamed: D55.1 (K), R55.2
unnamed: D55.2 (A), U8.6 (Q6)
unnamed: D56.1 (K), R56.2
unnamed: D56.2 (A), U8.7 (Q7)
unnamed: D57.1 (K), R57.2
unnamed: D57.2 (A), U9.15 (Q0)
unnamed: D58.1 (K), R58.2
unnamed: D58.2 (A), U9.1 (Q1)
unnamed: D59.1 (K), R59.2
unnamed: D59.2 (A), U9.2 (Q2)
unnamed: D60.1 (K), R60.2
unnamed: D60.2 (A), U9.3 (Q3)
unnamed: D61.1 (K), R61.2
unnamed: D61.2 (A), U9.4 (Q4)
unnamed: D62.1 (K), R62.2
unnamed: D62.2 (A), U9.5 (Q5)
unnamed: D63.1 (K), R63.2
unnamed: D63.2 (A), U9.6 (Q6)
unnamed: D64.1 (K), R64.2
unnamed: D64.2 (A), U9.7 (Q7)
unnamed: D65.1 (K), R65.2
unnamed: D65.2 (A), U10.15 (Q0)
unnamed: D66.1 (K), R66.2
unnamed: D66.2 (A), U10.1 (Q1)
unnamed: D67.1 (K), R67.2
unnamed: D67.2 (A), U10.2 (Q2)
unnamed: D68.1 (K), R68.2
unnamed: D68.2 (A), U10.3 (Q3)
unnamed: D69.1 (K), R69.2
unnamed: D69.2 (A), U10.4 (Q4)
unnamed: D70.1 (K), R70.2
unnamed: D70.2 (A), U10.5 (Q5)
unnamed: D71.1 (K), R71.2
unnamed: D71.2 (A), U10.6 (Q6)
unnamed: D72.1 (K), R72.2
unnamed: D72.2 (A), U10.7 (Q7)
unnamed: D73.1 (K), R73.2
unnamed: D73.2 (A), U11.15 (Q0)
unnamed: D74.1 (K), R74.2
unnamed: D74.2 (A), U11.1 (Q1)
unnamed: D75.1 (K), R75.2
unnamed: D75.2 (A), U11.2 (Q2)
unnamed: D76.1 (K), R76.2
unnamed: D76.2 (A), U11.3 (Q3)
unnamed: D77.1 (K), R77.2
unnamed: D77.2 (A), U11.4 (Q4)
unnamed: D78.1 (K), R78.2
unnamed: D78.2 (A), U11.5 (Q5)
unnamed: D79.1 (K), R79.2
unnamed: D79.2 (A), U11.6 (Q6)
unnamed: D80.1 (K), R80.2
unnamed: D80.2 (A), U11.7 (Q7)
unnamed: D81.1 (K), R81.2
unnamed: D81.2 (A), U12.15 (Q0)
unnamed: D82.1 (K), R82.2
unnamed: D82.2 (A), U12.1 (Q1)
unnamed: D83.1 (K), R83.2
unnamed: D83.2 (A), U12.2 (Q2)
unnamed: D84.1 (K), R84.2
unnamed: D84.2 (A), U12.3 (Q3)
unnamed: D85.1 (K), R85.2
unnamed: D85.2 (A), U12.4 (Q4)
unnamed: D86.1 (K), R86.2
unnamed: D86.2 (A), U12.5 (Q5)
unnamed: D87.1 (K), R87.2
unnamed: D87.2 (A), U12.6 (Q6)
unnamed: D88.1 (K), R88.2
unnamed: D88.2 (A), U12.7 (Q7)
unnamed: D89.1 (K), R89.2
unnamed: D89.2 (A), U13.15 (Q0)
unnamed: D90.1 (K), R90.2
unnamed: D90.2 (A), U13.1 (Q1)
unnamed: D91.1 (K), R91.2
unnamed: D91.2 (A), U13.2 (Q2)
unnamed: D92.1 (K), R92.2
unnamed: D92.2 (A), U13.3 (Q3)
unnamed: D93.1 (K), R93.2
unnamed: D93.2 (A), U13.4 (Q4)
unnamed: D94.1 (K), R94.2
unnamed: D94.2 (A), U13.5 (Q5)
unnamed: D95.1 (K), R95.2
unnamed: D95.2 (A), U13.6 (Q6)
unnamed: D96.1 (K), R96.2
unnamed: D96.2 (A), U13.7 (Q7)
unnamed: D97.1 (K), R97.2
unnamed: D97.2 (A), U14.15 (Q0)
unnamed: D98.1 (K), R98.2
unnamed: D98.2 (A), U14.1 (Q1)
unnamed: D99.1 (K), R99.2
unnamed: D99.2 (A), U14.2 (Q2)
unnamed: D100.1 (K), R100.2
unnamed: D100.2 (A), U14.3 (Q3)
unnamed: D101.1 (K), R101.2
unnamed: D101.2 (A), U14.4 (Q4)
unnamed: D102.1 (K), R102.2
unnamed: D102.2 (A), U14.5 (Q5)
unnamed: D103.1 (K), R103.2
unnamed: D103.2 (A), U14.6 (Q6)
unnamed: D104.1 (K), R104.2
unnamed: D104.2 (A), U14.7 (Q7)
unnamed: D105.1 (K), R105.2
unnamed: D105.2 (A), U15.15 (Q0)
unnamed: D106.1 (K), R106.2
unnamed: D106.2 (A), U15.1 (Q1)
unnamed: D107.1 (K), R107.2
unnamed: D107.2 (A), U15.2 (Q2)
unnamed: D108.1 (K), R108.2
unnamed: D108.2 (A), U15.3 (Q3)
unnamed: D109.1 (K), R109.2
unnamed: D109.2 (A), U15.4 (Q4)
unnamed: D110.1 (K), R110.2
unnamed: D110.2 (A), U15.5 (Q5)
unnamed: D111.1 (K), R111.2
unnamed: D111.2 (A), U15.6 (Q6)
unnamed: D112.1 (K), R112.2
unnamed: D112.2 (A), U15.7 (Q7)
unnamed: D113.1 (K), R113.2
unnamed: D113.2 (A), U16.15 (Q0)
unnamed: D114.1 (K), R114.2
unnamed: D114.2 (A), U16.1 (Q1)
unnamed: D115.1 (K), R115.2
unnamed: D115.2 (A), U16.2 (Q2)
unnamed: D116.1 (K), R116.2
unnamed: D116.2 (A), U16.3 (Q3)
unnamed: D117.1 (K), R117.2
unnamed: D117.2 (A), U16.4 (Q4)
unnamed: D118.1 (K), R118.2
unnamed: D118.2 (A), U16.5 (Q5)
unnamed: D119.1 (K), R119.2
unnamed: D119.2 (A), U16.6 (Q6)
unnamed: D120.1 (K), R120.2
unnamed: D120.2 (A), U16.7 (Q7)
unnamed: D121.1 (K), R121.2
unnamed: D121.2 (A), U17.15 (Q0)
unnamed: D122.1 (K), R122.2
unnamed: D122.2 (A), U17.1 (Q1)
unnamed: D123.1 (K), R123.2
unnamed: D123.2 (A), U17.2 (Q2)
unnamed: D124.1 (K), R124.2
unnamed: D124.2 (A), U17.3 (Q3)
unnamed: D125.1 (K), R125.2
unnamed: D125.2 (A), U17.4 (Q4)
unnamed: D126.1 (K), R126.2
unnamed: D126.2 (A), U17.5 (Q5)
unnamed: D127.1 (K), R127.2
unnamed: D127.2 (A), U17.6 (Q6)
unnamed: D128.1 (K), R128.2
unnamed: D128.2 (A), U17.7 (Q7)
unnamed: D129.1 (K), R129.2
unnamed: D129.2 (A), U18.15 (Q0)
unnamed: D130.1 (K), R130.2
unnamed: D130.2 (A), U18.1 (Q1)
unnamed: D131.1 (K), R131.2
unnamed: D131.2 (A), U18.2 (Q2)
unnamed: D132.1 (K), R132.2
unnamed: D132.2 (A), U18.3 (Q3)
unnamed: D133.1 (K), R133.2
unnamed: D133.2 (A), U18.4 (Q4)
unnamed: D134.1 (K), R134.2
unnamed: D134.2 (A), U18.5 (Q5)
unnamed: D135.1 (K), R135.2
unnamed: D135.2 (A), U18.6 (Q6)
unnamed: D136.1 (K), R136.2
unnamed: D136.2 (A), U18.7 (Q7)
unnamed: D137.1 (K), R137.2
unnamed: D137.2 (A), U19.15 (Q0)
unnamed: D138.1 (K), R138.2
unnamed: D138.2 (A), U19.1 (Q1)
unnamed: D139.1 (K), R139.2
unnamed: D139.2 (A), U19.2 (Q2)
unnamed: D140.1 (K), R140.2
unnamed: D140.2 (A), U19.3 (Q3)
unnamed: D141.1 (K), R141.2
unnamed: D141.2 (A), U19.4 (Q4)
unnamed: D142.1 (K), R142.2
unnamed: D142.2 (A), U19.5 (Q5)
unnamed: D143.1 (K), R143.2
unnamed: D143.2 (A), U19.6 (Q6)
unnamed: D144.1 (K), R144.2
unnamed: D144.2 (A), U19.7 (Q7)
unnamed: D145.1 (K), R145.2
unnamed: D145.2 (A), U20.15 (Q0)
unnamed: D146.1 (K), R146.2
unnamed: D146.2 (A), U20.1 (Q1)
unnamed: D147.1 (K), R147.2
unnamed: D147.2 (A), U20.2 (Q2)
unnamed: D148.1 (K), R148.2
unnamed: D148.2 (A), U20.3 (Q3)
unnamed: D149.1 (K), R149.2
unnamed: D149.2 (A), U20.4 (Q4)
unnamed: D150.1 (K), R150.2
unnamed: D150.2 (A), U20.5 (Q5)
unnamed: D151.1 (K), R151.2
unnamed: D151.2 (A), U20.6 (Q6)
unnamed: D152.1 (K), R152.2
unnamed: D152.2 (A), U20.7 (Q7)
unnamed: D153.1 (K), R153.2
unnamed: D153.2 (A), U21.15 (Q0)
unnamed: D154.1 (K), R154.2
unnamed: D154.2 (A), U21.1 (Q1)
unnamed: D155.1 (K), R155.2
unnamed: D155.2 (A), U21.2 (Q2)
unnamed: D156.1 (K), R156.2
unnamed: D156.2 (A), U21.3 (Q3)
unnamed: D157.1 (K), R157.2
unnamed: D157.2 (A), U21.4 (Q4)
unnamed: D158.1 (K), R158.2
unnamed: D158.2 (A), U21.5 (Q5)
unnamed: D159.1 (K), R159.2
unnamed: D159.2 (A), U21.6 (Q6)
unnamed: D160.1 (K), R160.2
unnamed: D160.2 (A), U21.7 (Q7)
unnamed: D161.1 (K), R161.2
unnamed: D161.2 (A), U22.15 (Q0)
unnamed: D162.1 (K), R162.2
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

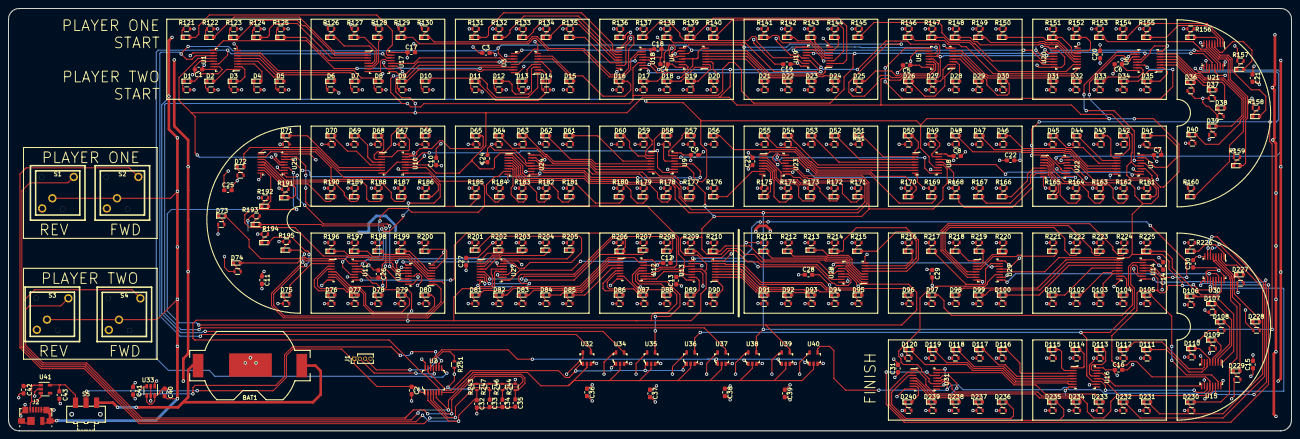
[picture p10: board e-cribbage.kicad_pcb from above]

Board: 2 copper layers, 304.8 x 100.3 mm, 577 parts (0 on the bottom side), 534 nets.

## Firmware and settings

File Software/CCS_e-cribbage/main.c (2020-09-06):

//******************************************************************************
//  MSP430F2012 LED cribbage board - software
//
//               MSP430F2012
//            -----------------
//        /|\|                 |
//         | |                 |
//         --|RST              |
//           |                 |
//           |             P1.0|<--S1
//           |             P1.1|<--S2
//           |             P1.2|<--S3
//           |             P1.3|<--S4
//           |                 |
//           |                 |     ^   LED TRACKS
//           |                 |     |  -------------
//           |                 |     |-|VDD          |
//           |             P1.6|------>|DATA         |
//           |             P1.5|------>|CLK          |
//           |             P1.4|------>|RCLK         |
//           |                 |       |             |
//           |             P2.6|------>|LE1          |
//           |             P2.7|------>|LE2          |
//           |                 |       |             |
//           |                 |
//           |                 |        -------------
//           |             P1.7|------>|VSW          |
//           |                 |       |             |
//
// 1 - VCC
// 2 - S1           (P1.0)
// 3 - S2           (P1.1)
// 4 - S3           (P1.2)
// 5 - S4           (P1.3)
// 6 - RCLK         (P1.4)
// 7 - CLK          (P1.5)
// 8 - DATA         (P1.6)
// 9 - VSW          (P1.7)
// 10 - JTAG - RST
// 11 - JTAG - TCK
// 12 - LE2         (P2.7)
// 13 - LE1         (P2.6)
// 14 - GND
//
//
//  Travis Christle
//  JUNE 2020
//  Built with CCS Version: 10.1.0
//******************************************************************************
#include "msp430.h"
#include "stdbool.h"

//port1 bits
#define P1REV   BIT0                // S3
#define P1FWD   BIT1                // S4
#define P2REV   BIT2                // S1
#define P2FWD   BIT3                // S2
#define LE      BIT4                // RCLK
#define CLK     BIT5                // Clock
#define DATA    BIT6                // Data
#define VSW     BIT7                // 3V SW
//port2 bits
#define LE1     BIT6                // P1_EN
#define LE2     BIT7                // P2_EN

#define delay10us       1
#define delay100us      9
#define delay20ms       1850
#define five_minutes    20000
#define five_seconds    400
#define longpress       11000

//global definitions
unsigned int sleep_time=0;
unsigned int peg_time=0;
unsigned int button_time=0;
unsigned int playtime0=0;
unsigned int playtime1=0;
unsigned int P1pts = 0;
unsigned int P1pegA = 0;
unsigned int P1pegB = 0;
unsigned int P2pts = 0;
unsigned int P2pegA = 0;
unsigned int P2pegB = 0;
unsigned int P1gameswon = 0;
unsigned int P2gameswon = 0;
bool cur1Peg = false;
bool cur2Peg = false;
bool P1button_pressed = false;
bool P2button_pressed = false;
bool current_player1 = false;

//function declarations
void show_pegs(void);
void restart_game(void);
void restore_game(void);
void save_game(void);
void wait_for_input(void);
void show_winner_pattern(void);
void delay(unsigned int dcount);
void show_win_totals(void);
void show_playtimer(void);

// ******************************************************************************************
int main(void){
    // stop watchdog timer
    WDTCTL = WDTPW | WDTHOLD;

    //Configure Basic Clock
    BCSCTL1 = CALBC1_1MHZ;
    DCOCTL = CALDCO_1MHZ;

    //Peripheral Setup
    P1DIR |= LE + VSW + CLK + DATA;
    P2DIR |= LE1 + LE2;
    P2SEL = 0;
    P1IES |= P1REV + P1FWD + P2REV + P2FWD;

    //Enter Sleep
    P1OUT = 0;
    P2OUT = 0;
    P1IE |= P1REV + P1FWD + P2REV + P2FWD;    //enable interupts for wake up
    _BIS_SR(LPM4_bits + GIE);                 // Enter LPM4 w/interrupt

    return 0;
}

// ******************************************************************************************
void wait_for_input(void){
    //enable VSW
    P1OUT |= VSW;
    delay(delay20ms);
    show_pegs();
    //start sleep timer
    sleep_time=0;

    while(sleep_time<five_minutes){
        //reset button timer
        button_time=0;

        //Detect Button Press, Port1_input=P1IN
        while(P1REV & ~P1IN){
            P1button_pressed = true;
            if(button_time==0 && P1pts>0) P1pts--;
            button_time++;
            if(button_time==longpress) break;
            if(P1REV & ~P1IN && P2REV & ~P1IN) restart_game();
        }
        while(P1FWD & ~P1IN){
            P1button_pressed = true;
            if(button_time==0) P1pts++;
            //wait for release and count for long press (+5)
            if(button_time==longpress)
            {
                P1pts+=3;
                break;
            }
            button_time++;
            if(P1FWD & ~P1IN && P2FWD & ~P1IN) {save_game(); P1pts--;}
            if(P1FWD & ~P1IN && P1REV & ~P1IN) {show_win_totals(); P1pts--;}
        }
        while(P2REV & ~P1IN){
            P2button_pressed = true;
            if(button_time==0 && P2pts>0) P2pts--;
            button_time++;
            if(button_time==longpress) break;
            if(P1REV & ~P1IN && P2REV & ~P1IN) restart_game();
        }
        while(P2FWD & ~P1IN){
            P2button_pressed = true;
            if(button_time==0) P2pts++;
            //wait for release and count for long press (+5)
            if(button_time==longpress){
                P2pts+=3;
                break;
            }
            button_time++;
            if(P1FWD & ~P1IN && P2FWD & ~P1IN) {restore_game(); P2pts--;}
            if(P2FWD & ~P1IN && P2REV & ~P1IN) {show_playtimer(); P2pts--;}
        }
        //update pegs
        if(P1button_pressed || P2button_pressed){
            //alternate pegs and update peg values if points changed
            if(P1button_pressed){
                //switch pegs if player switched or peg_time > five_seconds
                if(current_player1==false || peg_time>five_seconds) cur1Peg ^= 1;
                if(cur1Peg) P1pegA = P1pts; else P1pegB = P1pts;
                if(P1pegA > P1pts) P1pegA = P1pts - 1;
                if(P1pegB > P1pts) P1pegB = P1pts - 1;
                if(P1pegA==P1pegB && cur1Peg) P1pegB--;
                if(P1pegA==P1pegB && ~cur1Peg) P1pegA--;
                current_player1 = true;
                }
            if(P2button_pressed){
                //switch pegs if player switched or peg_time > five_seconds
                if(current_player1==true  || peg_time>five_seconds) cur2Peg ^= 1;
                if(cur2Peg) P2pegA = P2pts; else P2pegB = P2pts;
                if(P2pegA > P2pts) P2pegA = P2pts - 1;
                if(P2pegB > P2pts) P2pegB = P2pts - 1;
                if(P2pegA==P2pegB && cur2Peg) P2pegB--;
                if(P2pegA==P2pegB && ~cur2Peg) P2pegA--;
                current_player1 = false;
                }
            P1button_pressed = false;
            P2button_pressed = false;
            sleep_time=0;
            peg_time=0;
            show_pegs();
        }
        //increment timers
        sleep_time++;
        peg_time++;
        playtime0++;
        if(playtime0==0xFFFF) playtime1++;
        delay(delay20ms);

        //check for winner
        if(P1pts >= 121 || P2pts >= 121) show_winner_pattern();
    }
    //save_game();
    P1OUT &= ~VSW;                            //disable VSW
    P1IFG &= ~P1REV & ~P1FWD & ~P2REV & ~P2FWD;
    _BIS_SR(LPM4_bits + GIE);                 // Enter LPM4 w/interrupt
}

// ******************************************************************************************
void show_pegs(void){
    unsigned int i=0;

    //Show Player 1 Pegs
    P2OUT = LE2;
    for(i=120; i>0; i--){
        if(i==P1pegA || i==P1pegB){
            P1OUT |= DATA;
            delay(delay10us);
            P1OUT |= CLK;
            P1OUT &= ~DATA;
            P1OUT &= ~CLK;
        }
        else{
            P1OUT |= CLK;   //~5us
            P1OUT &= ~CLK;
        }
    }
    P1OUT |= LE;
    delay(delay10us);
    P1OUT &= ~LE;
    P2OUT = 0;

    //Show Player 2 Pegs
    P2OUT = LE1;
    for(i=120; i>0; i--){
        if(i==P2pegA || i==P2pegB){
            P1OUT |= DATA;
            delay(delay10us);
            P1OUT |= CLK;
            P1OUT &= ~DATA;
            P1OUT &= ~CLK;
        }
        else{
            P1OUT |= CLK;
            P1OUT &= ~CLK;
        }
    }
    P1OUT |= LE;
    delay(delay10us);
    P1OUT &= ~LE;
    P2OUT = 0;
}

// ******************************************************************************************
void restart_game(void){
    //prevent unsigned overflow
    if(P1pegA > 121) P1pegA=1;
    if(P1pegB > 121) P1pegB=1;
    if(P2pegA > 121) P2pegA=1;
    if(P2pegB > 121) P2pegB=1;
    //show reverse LED walk pattern
    while((P1pegA+P1pegB+P2pegA+P2pegB) > 0){
        if(P1pegA > 0) P1pegA--;
        if(P1pegB > 0) P1pegB--;
        if(P2pegA > 0) P2pegA--;
        if(P2pegB > 0) P2pegB--;
        delay(delay20ms);
        show_pegs();
    }
    //Reset Peg Values
    P1pts = 0;
    P2pts = 0;
}

// ******************************************************************************************

void restore_game(void){
    //read points and peg values from FLASH information memory section C
    //char  value;                // 8-bit value to write to segment C
    char *Flash_ptr;            // Flash pointer

    FCTL2 = FWKEY + FSSEL0 + FN1;             // MCLK/3 for Flash Timing Generator
    //value = 0;                                // initialize value
    Flash_ptr = (char *) 0x1040;              // Initialize Flash pointer

    // *** ints need to be cast to char ***
    P1pegA = *Flash_ptr++;
    P1pegB = *Flash_ptr++;
    P1pts  = *Flash_ptr++;
    P2pegA = *Flash_ptr++;
    P2pegB = *Flash_ptr++;
    P2pts  = *Flash_ptr++;
    show_pegs();
}

// ******************************************************************************************
void save_game(void){
    //store points and peg values to FLASH information memory section C
    //char  value;                // 8-bit value to write to segment C
    char *Flash_ptr;            // Flash pointer

    FCTL2 = FWKEY + FSSEL0 + FN1;             // MCLK/3 for Flash Timing Generator
    //value = 0;                                // initialize value
    Flash_ptr = (char *) 0x1040;              // Initialize Flash pointer
    FCTL1 = FWKEY + ERASE;                    // Set Erase bit
    FCTL3 = FWKEY;                            // Clear Lock bit
    *Flash_ptr = 0;                           // Dummy write to erase Flash segment

    FCTL1 = FWKEY + WRT;                      // Set WRT bit for write operation

    // *** ints need to be cast to char ***
    *Flash_ptr++ = P1pegA;
    *Flash_ptr++ = P1pegB;
    *Flash_ptr++ = P1pts;
    *Flash_ptr++ = P2pegA;
    *Flash_ptr++ = P2pegB;
    *Flash_ptr++ = P2pts;
    *Flash_ptr++ = playtime1;

    FCTL1 = FWKEY;                            // Clear WRT bit
    FCTL3 = FWKEY + LOCK;                     // Set LOCK bit
}

// ******************************************************************************************
void show_winner_pattern(){
    //display pattern for winner
    if(P1pts >= 121){
        P1gameswon++;
        if(P2pts<91) P1gameswon++; //skunk
        P1pegA = 1;
        P1pegB = 2;
        while(P1pegB <= 120){
            P1pegA++;
            P1pegB++;
            delay(delay20ms);
            show_pegs();
        }
    }
    if(P2pts >= 121){
        P2gameswon++;
        if(P1pts<91) P2gameswon++; //skunk
        P2pegA = 1;
        P2pegB = 2;
        while(P2pegB <= 120){
            P2pegA++;
            P2pegB++;
            delay(delay20ms);
            show_pegs();
        }
    }
    //reset points
    P1pts = 0;
    P2pts = 0;
    P1pegA = 121-P1gameswon;
    P1pegB = 0;
    P2pegA = 121-P2gameswon;
    P2pegB = 0;
    show_pegs();
}

// ******************************************************************************************
void show_win_totals(void){
    unsigned int tempA = P1pegA;
    unsigned int tempB = P2pegA;
    P1pegA = 121-P1gameswon;
    P2pegA = 121-P2gameswon;
    show_pegs();
    //wait for release
    while (P1FWD & ~P1IN || P1REV & ~P1IN);// _NOP();
    P1pegA = tempA;
    P2pegA = tempB;
    show_pegs();
}

// ******************************************************************************************
void show_playtimer(void){
    unsigned int tempA = P1pegA;
    unsigned int tempB = P1pegB;
    P1pegA = 121-playtime1/8;
    P2pegA = 121-playtime1%8;
    show_pegs();
    //wait for release
    while (P1FWD & ~P1IN || P1REV & ~P1IN);// _NOP();
    P1pegA = tempA;
    P2pegA = tempB;
    show_pegs();
}

// ******************************************************************************************
void delay(unsigned int dcount){
    unsigned int d;
    for(d=dcount; d>0; d--) _NOP();
}

// ******************************************************************************************
// Port 1 interrupt service routine
#pragma vector=PORT1_VECTOR
__interrupt void Port_1(void){
    //wait until button is released after wake up
    while(P1IN!=0x0f);
    //while(P1REV & ~P1IN || P1FWD & ~P1IN || P2REV & ~P1IN || P2FWD & ~P1IN);
    wait_for_input();
}

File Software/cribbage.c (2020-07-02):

//******************************************************************************
//  MSP430F2012 LED cribbage board - software
//
//               MSP430F2012
//            -----------------
//        /|\|              XIN|-
//         | |                 |
//         --|RST          XOUT|-
//           |                 |
//           |             P1.0|<--S1
//           |             P1.1|<--S2
//           |             P1.2|<--S3
//           |             P1.3|<--S4
//           |                 |
//           |                 |     ^   LED TRACKS
//           |                 |     |  -------------
//           |                 |     |-|VDD          |
//           |             P1.6|------>|DATA         |
//           |             P1.5|------>|CLK          |
//           |                 |       |             |
//           |             P2.6|------>|LE1          |
//           |             P2.7|------>|LE2          |
//           |                 |       |             |
//
// 1 - VCC
// 2 - S1			(P1.0)
// 3 - S2			(P1.1)
// 4 - S3			(P1.2)
// 5 - S4			(P1.3)
// 6 - NC			(P1.4)
// 7 - CLK			(P1.5)
// 8 - DATA			(P1.6)
// 9 - NC			(P1.7)
// 10 - JTAG - RST
// 11 - JTAG - TCK
// 12 - LE2			(P2.7)
// 13 - LE1			(P2.6)
// 14 - GND
//
//
//  Travis Christle
//  JUNE 2020
//  Built with CCS Version: 6.1.1
//******************************************************************************
//#include "msp430f2012.h"
#include "msp430.h"
#include "stdbool.h"

#define TXD  BIT1                   // TXD on P1.5 to uart module
#define RXD  BIT2                   // RXD on P1.1 from uart module
#define LED  BIT0					// LED
#define LE   BIT3					// Latch Enable
#define FRST BIT4					// FPGA Reset
#define RF_BUF_EN BIT6				// ADC CLOCK Enable

#define Sync 0x55                   // Start byte for BT app message
#define Rx88 0x01
#define Rx89 0x04

#define Bit_time 104                // 115200 Baud, SMCLK=12MHz (12MHz/115200)=104+1
#define Bit_time_5 52               // Time for half a bit.

unsigned int i=0, j=0, k=0, l=0;    // General purpose counters
unsigned int pause = 20000;         // General purpose delay
unsigned int BitCnt;                // Bit count, used when transmitting byte
unsigned int TXByte = 0x0055;       // Value sent over UART when Transmit() is called
unsigned int RXByte = 0x0000;       // Value recieved once hasRecieved is set
unsigned int RXBuff[5] = {0, 0, 0, 0, 0};
unsigned int SPI_readback = 0;

bool isReceiving = false;           // Status for when the device is receiving
bool hasReceived = false;           // Lets the program know when a byte is received
bool echo = true;
bool temp = true;

// Function Definitions
void Transmit(void);
void Send_SPI(unsigned int reg, unsigned int data);
void burst_read(void);

// ******************************************************************************************

void main(void)
{

WDTCTL = WDTPW + WDTHOLD;   		        // Stop WDT

//Configure Basic Clock
BCSCTL1 = CALBC1_12MHZ;               		// Set range
DCOCTL = CALDCO_12MHZ;              		// SMCLK = DCO = 8MHz

//UART Setup
P1SEL = TXD;
P1OUT = TXD + LE + FRST;
P1DIR |= TXD + LED;
P1IES |= RXD;                      			 // RXD Hi/lo edge interrupt
P1IFG &= ~RXD;                		         // Clear RXD (flag) before enabling interrupt
P1IE |= RXD;                 			     // Enable RXD interrupt
P2OUT = RF_BUF_EN;
P2DIR = RF_BUF_EN;
P2SEL = 0;

//SPI Setup
P1DIR |= LE + FRST;                           		    // Set P1.1 for sync output
USICTL0 |= USIPE7 + USIPE6 + USIPE5 + USIMST + USIOE;   // Port, SPI Master
//USICTL1 |= USIIE; //USICKPH + USIIE;      		    // Counter interrupt, flag remains set
USICKCTL = USIDIV_2 + USISSEL_2; 				        // /2 SMCLK
USICTL0 &= ~USISWRST;                     		    	// USI released for operation

//Startup Blinky
for(j=0; j<4; j++)                	      	 	        // Blink green LED for power up & ready
	{
	P1OUT |= LED;
	for(i=1; i<=pause; i++);
	P1OUT ^= LED;
	for(i=1; i<=pause; i++);
	}

__bis_SR_register(GIE);

while(1)                          			 // Begin loop
	{

	}
}

// ****************************************************************************************
void Send_SPI(unsigned int reg, unsigned int data)
{

	P1OUT &= ~LE;                         // Latch EN

	USISRL = reg;			   			    // set register 1st byte
	USICNT = 8;                             // re-load counter
	while (!(USIIFG & USICTL1));            // Counter clear?
	USISRL = data;			 			    // set register 2nd byte
	USICNT = 8;                             // re-load counter
	while (!(USIIFG & USICTL1));            // Counter clear?

	P1OUT |= LE;

	SPI_readback = USISRL;

}
//*****************************************************************************************
void Transmit()
{
	if(echo) {
		while(isReceiving);                // Wait for RX completion
		CCTL0 = OUT;                       // TXD Idle as Mark
		TACTL = TASSEL_2 + MC_2;           // SMCLK, continuous mode

		BitCnt = 0xA;                      // Load Bit counter, 8 bits + ST/SP
		CCR0 = TAR;                        // Initialize compare register

		CCR0 += Bit_time;                  // Set time till first bit
		TXByte |= 0x100;                   // Add stop bit to TXByte (which is logical 1)
		TXByte = TXByte << 1;              // Add start bit (which is logical 0)

		CCTL0 = CCIS0 + OUTMOD0 + CCIE;    // Set signal, intial value, enable interrupts
		while ( CCTL0 & CCIE );            // Wait for previous TX completion
	}
}
//*****************************************************************************************
void burst_read()
{
	unsigned int reg1, reg2, reg3, reg4, reg5;

	P1OUT &= ~LE;                         // Latch EN

	USISRL = 0x21;			   			    // set register 1st byte
	USICNT = 8;                             // re-load counter
	while (!(USIIFG & USICTL1));            // Counter clear?

	USISRL = 0x00;			 			    // set register 2nd byte
	USICNT = 8;                             // re-load counter
	while (!(USIIFG & USICTL1));            // Counter clear?
	reg1 = USISRL;

	USISRL = 0x00;			 			    // set register 2nd byte
	USICNT = 8;                             // re-load counter
	while (!(USIIFG & USICTL1));            // Counter clear?
	reg2 = USISRL;

	USISRL = 0x00;			 			    // set register 2nd byte
	USICNT = 8;                             // re-load counter
	while (!(USIIFG & USICTL1));            // Counter clear?
	reg3 = USISRL;

	USISRL = 0x00;			 			    // set register 2nd byte
	USICNT = 8;                             // re-load counter
	while (!(USIIFG & USICTL1));            // Counter clear?
	reg4 = USISRL;

	USISRL = 0x00;			 			    // set register 2nd byte
	USICNT = 8;                             // re-load counter
	while (!(USIIFG & USICTL1));            // Counter clear?
	reg5 = USISRL;

	P1OUT |= LE;
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

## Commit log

2020-06-29 PBA parts placement
    [e-cribbage-2020-06-27-18-09-00.sch, e-cribbage-2020-06-27-18-17-20.sch, e-cribbage.kicad_pcb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]
2020-06-29 reduced 0603 footprints
    [e-cribbage.kicad_pcb, e-cribbage.sch]
2020-06-29 power and ground planes added 471 nets unconnected
    [e-cribbage.kicad_pcb, e-cribbage.sch]
2020-06-29 updated schematic
2020-06-30 preliminary part placement and route
    [e-cribbage.kicad_pcb, e-cribbage.sch]
2020-06-30 updated digikey footprints with 3d models
    [TSSOP-14_4.4x5mm_P0.65mm.step, TSSOP-16_4.4x5mm_P0.65mm.step, e-cribbage.kicad_pcb]
2020-06-30 MSP430 code examples and template added re-using UART to SPI program as starting point
2020-06-30 clock fanout added to schematic
    [e-cribbage.kicad_pcb, e-cribbage.sch]
2020-07-01 OE pulled low
    [e-cribbage.kicad_pcb, e-cribbage.sch]
2020-07-01 added datasheets and BOM
2020-07-01 added FET connector
    [e-cribbage.kicad_pcb, e-cribbage.sch]
2020-07-01 created local library
    [e-cribbage.kicad_pcb, e-cribbage.sch]
2020-07-01 schematic fixes + routes + battery clip
    [e-cribbage.kicad_pcb, e-cribbage.sch]
2020-07-01 clock routing
    [e-cribbage.kicad_pcb]
2020-07-02 schematic fix + more clock routes
    [e-cribbage.kicad_pcb, e-cribbage.sch]
2020-07-02 more clock routes
    [e-cribbage.kicad_pcb]
2020-07-05 initial routing complete
    [e-cribbage.kicad_pcb]
2020-07-09 Schematic Update: USB Connector, Power Switch, Load Switch
    [e-cribbage.sch]
2020-07-17 schematic updates - added 3.3V Linear Regulator
    [e-cribbage.sch]
2020-07-17 Layout - routed switch, usb, linear reg
    [e-cribbage.kicad_pcb]
2020-07-22 Schematic Updates - SMT Batt/USB switch, 3.3V LDO, RCLCK connections to shift regs Library Updates - added 3D models for switches and battery
    [e-cribbage.sch]
2020-07-24 Layout: routed USB power and switch, silkscreen
    [e-cribbage.kicad_pcb]
2020-07-26 Finished RCLK routes
    [e-cribbage.kicad_pcb]
2020-07-29 implemented sleep timer and wake up
2020-07-29 implemented restart, fixed point subraction bug, code cleanup
    [main.c]
2020-07-29 fixed broken connection on U24-14
    [e-cribbage.kicad_pcb, e-cribbage.sch]
2020-07-29 BOM export from Schematic
    [e-cribbage.csv]
2020-07-30 schematic and parts cleanup
    [e-cribbage.sch]
2020-07-30 BOM and parts updates
    [2020-07-30T125058.xlsx, e-cribbage.xls]
2020-07-30 replaced S1 with TH push button
    [e-cribbage.kicad_pcb]
2020-07-30 library and layout cleanup
    [TSSOP-14_4.4x5mm_P0.65mm.step, TSSOP-16_4.4x5mm_P0.65mm.step, e-cribbage.kicad_pcb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]
2020-07-30 gerbers generated PCB order W100671ASM2 submitted
    [e-cribbage-B_Cu.gbr, e-cribbage-B_Mask.gbr, e-cribbage-Edge_Cuts.gbr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]
2020-08-12 debug and feature adds
    fixed backward pegging
    fixed P1/P2 swap
    fixed backward counting
    added play timer
    added game win counters
    added peg swap timer
    disabled gave save/restore
    [main.c]
2020-09-03 code cleanup, fixed power-up glitch, optimized long press time
    [main.c]
2020-09-06 code clean up and bug fixes
    swapped player buttons and LE1/LE2 assignments
    fixed win total display bug
    fixed wakeup bug
    [main.c]

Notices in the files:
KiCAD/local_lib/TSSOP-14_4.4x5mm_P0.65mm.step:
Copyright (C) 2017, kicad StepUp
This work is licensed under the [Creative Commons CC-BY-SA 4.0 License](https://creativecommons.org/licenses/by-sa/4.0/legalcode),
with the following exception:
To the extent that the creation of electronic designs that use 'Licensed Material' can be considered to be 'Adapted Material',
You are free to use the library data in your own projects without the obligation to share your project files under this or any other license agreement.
